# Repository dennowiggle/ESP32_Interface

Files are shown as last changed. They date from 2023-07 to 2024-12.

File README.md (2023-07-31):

# ESP32_Interface
Facilitate learning the Z80 Retro! hardware and software.

## Feature list:
ESP32-s3 based board to provide WiFi enabled features.
* RS232 connection to main Z80-Retro console via cable for telnet console access
* RS232 connection to Z80-Retro Aux com port via cable for future WiFi enabled serial download.
* Z80 bus programmer using MCP23S17 SPI IO expander devices.
  - facilitates faster Z80 bus access at 10Mhz SPI rate. 
    - Serial access still relatively slow but 25x I2C.
  - Program Flash without the need for a Raspberry Pi.
  - Might be possible to program areas of SRAM memory e.g. future WiFi file download.
* Off-board SPI using header connection to future board(s) such as FPGA video card.
  - programming FPGA plus additional SPI-FPGA debug features if needed.
* One byte, 8 bit, message register implemented in logic for handshaking with Z80.
  - uses IORQ addreess line 0xA4.
* USB OTG is present in hardware.
* SD card slot for future possiblities.

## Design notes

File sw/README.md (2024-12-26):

# ESP32 Z80 Retro! Programmer Software
Facilitate learning the Z80 Retro! hardware and software.

## Information:
The ESP32-S3 SW is in a platformio project format. If using VS Code there is a platformio plugin. Upon opening the project folder the project should self configure.

## ESP32-S3-DevkitC
* There are two versions of this dev kit supported - V1 and V1.1. If using a v1.1 module make the following change in `defines.h` for the LED to operate as expected as the two modules use different GPIO pins.

  ```#define ESP32_S3_DEVKITC_VERSION (1.1)```

## ESP32 Module Programming
* To program the board use the USB JTAG port on the module.
  - First upload the filesystem.
  - Then upload the code.
  
## WiFi Setup
* On first boot the module enters WiFi host AP mode.
  - Connect local computer to WiFi network "Z80-programmer" with password "Z80-Retro!"
  - Assign local computer IP address 192.168.4.10
  - Z80-Retro! WiFi setup IP address is 192.168.4.1
  - Open a webpage at address http://192.168.4.1 to set the WiFi parameters for WiFi client mode in the local network environment.
  - Power cycle.
  
![ESP32 Z80 Retro Programmer! WiFi Setup](docs/WiFi_Setup.jpg "WiFi Setup")

## Web Page Use
* On the local WiFi router find the new IP address that the DHCP server assigned.
* Connect local computer to local WiFi network
* Open webage and enter the IP address assigned by DHCP server to the Z80-Programmer! 

![ESP32 Z80 Retro Programmer! WiFi Setup](docs/Z80-Programmer_WebPage.jpg "Web Page Use")

## Remote Wireless Console - to ESP32 Z80 Programmer!
* There is Telnet console access to the ESP32 Z80-Programmer at the same IP address on port 2323

![Remote Wireless Console - to ESP32 Z80 Programmer!](docs/Telnet_ESP32_Port_2323.jpg "Remote Programmer Console")

## Remote Wireless Console - to Z80 Retro! Console Port
* There is Telnet console access to the Z80 Retro at the same IP address on port 23
* Connect the Z80 Retro Console port to the first ESP32 9 pin DIN. It uses the same cable as used originally in the Z80 Retro project.
* Using console access to the ESP32 Z80 Programmer configure the baud rate to match thhat of the Z80 Programmer.

![Remote Wireless Console - to Z80 Retro! Console Port](docs/Telnet_Z80Retro_Port_23.jpg "Remote Z80 Retro! Console")

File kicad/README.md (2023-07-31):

# ESP32_Interface
Facilitate learning the Z80 Retro! hardware and software.

## Description
This project adds a WiFi interface to the Z80 Retro! It has been used to facilitate telnet to the Z80 serial port, and programming the Z80 Retro! Flash memory via serial or telnet xmodem or a web interface.

## Top View
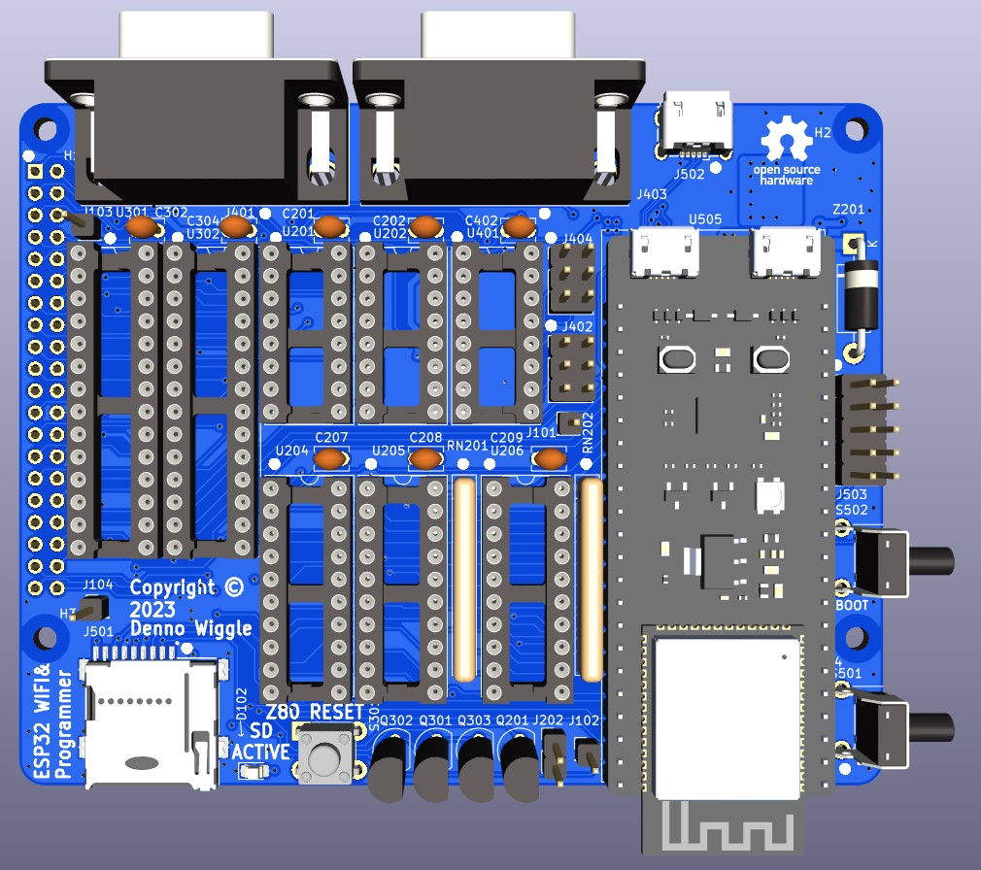
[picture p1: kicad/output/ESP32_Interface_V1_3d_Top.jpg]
ESP32 Interface Top View Board Image Top View of the ESP32 Interface Board


## Bottom View
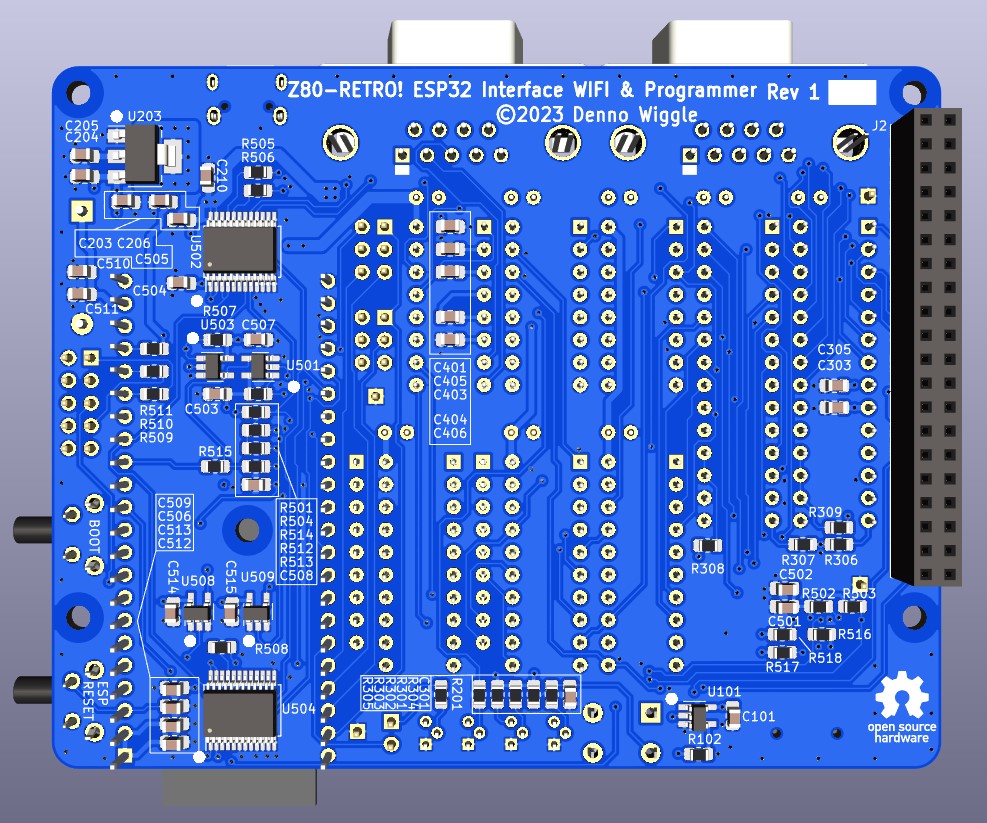
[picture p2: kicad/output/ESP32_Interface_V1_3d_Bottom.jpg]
ESP32 Interface Bottom View Board Image Bottom View of the ESP32 Interface Board


## ESP32 Interface Board Rev 1.0 Release Notes

1. The 'output' directory contains the BOM, netlist, and PDF schematic.

2. Board design used KiCad 7.0.2.

3. Silkscreen box on back side should extend around R501.

4. Holes for U505, the ESP32 module, are tight but it is possible to fit the module in. Larger pin holes would be preferred.

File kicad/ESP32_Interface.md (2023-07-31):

# ESP32_Interface.kicad_sch

## 7/9/2023 3:29:03 PM

## Eeschema 7.0.2

## Component Count:112

Ref | Qty | Value | Digikey | Datasheet | Description
----|-----|-------|---------|-----------|------------
C101, C204, C205, C403, C404, C405, C406, C501, C503, C504, C505, C506, C507, C509, C510, C512, C514, C515 | 18 | 100nF | 732-8045-1-ND | https://www.we-online.com/katalog/datasheet/885012207045.pdf | Unpolarized capacitor, small symbol
C201, C202, C207, C208, C209, C302, C304, C402 | 8 | 100n | 399-9859-1-ND‎ | https://api.kemet.com/component-edge/download/specsheet/C315C104M5U5TA7303.pdf | Unpolarized capacitor, small symbol
C203, C206, C210, C301, C303, C305, C401, C502, C511, C513 | 10 | 10uF | 1276-6455-1-ND | https://media.digikey.com/pdf/Data%20Sheets/Samsung%20PDFs/CL21A106KOQNNNG_Spec.pdf | Unpolarized capacitor, small symbol
C508 | 1 | DNL | 732-8045-1-ND | https://www.we-online.com/katalog/datasheet/885012207045.pdf | Unpolarized capacitor, small symbol
D102 | 1 | LTST-C170KGKT | 160-1414-1-ND | https://optoelectronics.liteon.com/upload/download/DS22-2000-073/LTST-C170KGKT.pdf | LED RED CLEAR SMD
H1, H2, H3, H4, H5 | 5 | MountingHole |  | ~ | Mounting Hole without connection
J2 | 1 | Conn_02x20_Counter_Clockwise |  | https://www.amazon.com/gp/product/B084Q4W1PW/ref=ppx_yo_dt_b_search_asin_title?ie=UTF8&psc=1 | Generic connector, double row, 02x20, counter clockwise pin numbering scheme (similar to DIP package numbering), script generated (kicad-library-utils/schlib/autogen/connector/)
J101, J102, J103, J104 | 4 | Conn_01x01 |  | ~ | Generic connector, single row, 01x01, script generated (kicad-library-utils/schlib/autogen/connector/)
J202 | 1 | Conn_01x02 | 2057-PH1-02-UA-ND | https://app.adam-tech.com/products/download/data_sheet/201605/ph1-xx-ua-data-sheet.pdf | Generic connector, single row, 01x02, script generated (kicad-library-utils/schlib/autogen/connector/)
J401, J403 | 2 | DB9_Male_MountingHoles | AE10970-ND | http://www.assmann-wsw.com/uploads/datasheets/ASS_4888_CO.pdf | 
J402, J404 | 2 | Conn_02x03 | 2057-PH2-06-UA-ND | https://app.adam-tech.com/products/download/data_sheet/202065/ph2-xx-ua-data-sheet.pdf | Generic connector, double row, 02x03, odd/even pin numbering scheme (row 1 odd numbers, row 2 even numbers), script generated (kicad-library-utils/schlib/autogen/connector/)
J501 | 1 | GCT_MEM2075-00-140-01-A_DP | 2073-MEM2075-00-140-01-ACT-ND | https://gct.co/files/specs/mem2075-spec.pdf | 
J502 | 1 | USB_B_Micro | 732-5960-1-ND | https://www.we-online.com/components/products/datasheet/629105150521.pdf | USB Micro Type B connector
J503 | 1 | Conn_02x05_Right_Angle | 2057-PH2RA-10-UA-ND | https://app.adam-tech.com/products/download/data_sheet/200508/ph2ra-xx-ua-data-sheet.pdf | Generic connector, double row, 02x05, odd/even pin numbering scheme (row 1 odd numbers, row 2 even numbers), script generated (kicad-library-utils/schlib/autogen/connector/)
Q201, Q301, Q302, Q303 | 4 | PN2222 | 1514-PN2222APBFREE-ND | https://my.centralsemi.com/datasheets/PN2221-2222A.PDF | NPN transistor, emitter/base/collector
R102, R201, R305 | 3 | 1K | 311-1.0KARCT-ND | https://www.yageo.com/upload/media/product/productsearch/datasheet/rchip/PYu-RC_Group_51_RoHS_L_12.pdf | Resistor, US symbol
R301, R302, R303, R308, R309, R501, R502, R503, R504, R507, R511, R516, R517, R518 | 14 | 10K | 311-10KARCT-ND | https://www.yageo.com/upload/media/product/productsearch/datasheet/rchip/PYu-RC_Group_51_RoHS_L_12.pdf | Resistor, US symbol
R304 | 1 | 47K | 311-47KARCT-ND | https://www.yageo.com/upload/media/product/productsearch/datasheet/rchip/PYu-RC_Group_51_RoHS_L_12.pdf | Resistor, US symbol
R306, R307, R505, R506, R508, R509, R510 | 7 | 33R | 311-33ARCT-ND | https://www.yageo.com/upload/media/product/productsearch/datasheet/rchip/PYu-RC_Group_51_RoHS_L_12.pdf | Resistor, US symbol
R512, R513 | 2 | 0R | 311-0.0ARCT-ND | https://www.yageo.com/upload/media/product/productsearch/datasheet/rchip/PYu-RC_Group_51_RoHS_L_12.pdf | Resistor, US symbol
R514, R515 | 2 | DNL | 311-0.0ARCT-ND | https://www.yageo.com/upload/media/product/productsearch/datasheet/rchip/PYu-RC_Group_51_RoHS_L_12.pdf | Resistor, US symbol
RN201, RN202 | 2 | 10K | 4609X-101-103LF-ND | https://www.bourns.com/docs/Product-Datasheets/4600x.pdf | 8 resistor network, star topology, bussed resistors, small symbol
S301 | 1 | 1825910-6 | 450-1650-ND | https://www.te.com/commerce/DocumentDelivery/DDEController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 | SWITCH TACTILE SPST-NO 0.05A 24V
S501 | 1 | 1-1825027-2 | 1-1825027-2-ND | https://www.te.com/commerce/DocumentDelivery/DDEController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 | SWITCH TACTILE SPST-NO 0.05A 24V
S502 | 1 | 1825027-8 | 450-1657-ND | https://www.te.com/commerce/DocumentDelivery/DDEController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 | SWITCH TACTILE SPST-NO 0.05A 24V
U101 | 1 | SN74LVC1G04DBVR | 296-11599-1-ND | http://www.ti.com/general/docs/suppproductinfo.tsp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 | IC INVERTER 1CH 1-INP SOT23-5
U201, U202 | 2 | 74LS138 | 296-1728-5-ND | http://www.ti.com/lit/gpn/sn74LS138 | Decoder 3 to 8 active low outputs
U203 | 1 | NCP1117LPST33T3G | NCP1117LPST33T3GOSCT-ND | https://www.onsemi.com/pdf/datasheet/ncp1117lp-d.pdf | IC REG LINEAR 3.3V 1A SOT223
U204 | 1 | 74HC374 | 296-12806-5-ND | https://www.ti.com/lit/ds/symlink/cd74hct374.pdf | 8-bit Register, 3-state outputs
U205 | 1 | 74LS244 | 296-1653-5-ND | https://www.ti.com/lit/ds/symlink/sn74ls241.pdf | Octal Buffer and Line Driver With 3-State Output, active-low enables, non-inverting outputs
U206 | 1 | 74LVC245A | 296-8503-5-ND | http://www.ti.com/lit/ds/symlink/sn74lvc245a.pdf | Octal BUS Transceivers, 3-State outputs
U301, U302 | 2 | MCP23S17_SP | MCP23S17-E/SP-ND | http://ww1.microchip.com/downloads/en/DeviceDoc/20001952C.pdf | 16-bit I/O expander, SPI, interrupts, w pull-ups, SPDIP-28
U401 | 1 | ICL3232CPZ | ICL3232CPZ-ND‎ | https://www.renesas.com/us/en/document/dst/icl3221-icl3222-icl3223-icl3232-icl3241-icl3243-datasheet | 3.0V to 5.5V, Low-Power, up to 1Mbps, True RS-232 Transceivers Using Four 0.1μF External Capacitors
U501, U503, U508, U509 | 4 | SN74LVC1G125DBVR | 296-11603-1-ND | http://www.ti.com/general/docs/suppproductinfo.tsp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 | IC BUF NON-INVERT 5.5V SOT23-5
U502, U504 | 2 | SN74LVC8T245DBR | 296-21065-1-ND | https://www.ti.com/lit/ds/symlink/sn74lvc8t245.pdf | Octal BUS Transceivers, 3-State outputs
U505 | 1 | ESP32-S3-DevKitC | 1965-ESP32-S3-DEVKITC-1-N8R2-ND | https://docs.espressif.com/projects/esp-idf/en/latest/esp32s3/hw-reference/esp32s3/user-guide-devkitc-1.html | ESP32-S3-DevKitC
Z201 | 1 | SA5.0A | SA5.0ALFCT-ND | https://www.littelfuse.com/~/media/electronics/datasheets/tvs_diodes/littelfuse_tvs_diode_sa_datasheet.pdf.pdf | TVS DIODE 5VWM 9.2VC DO214AA

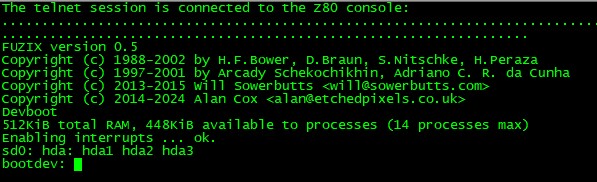
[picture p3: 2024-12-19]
sw/docs/Telnet_Z80Retro_Port_23.jpg

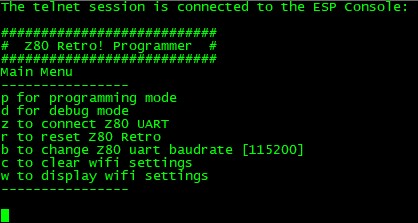
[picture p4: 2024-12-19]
sw/docs/Telnet_ESP32_Port_2323.jpg

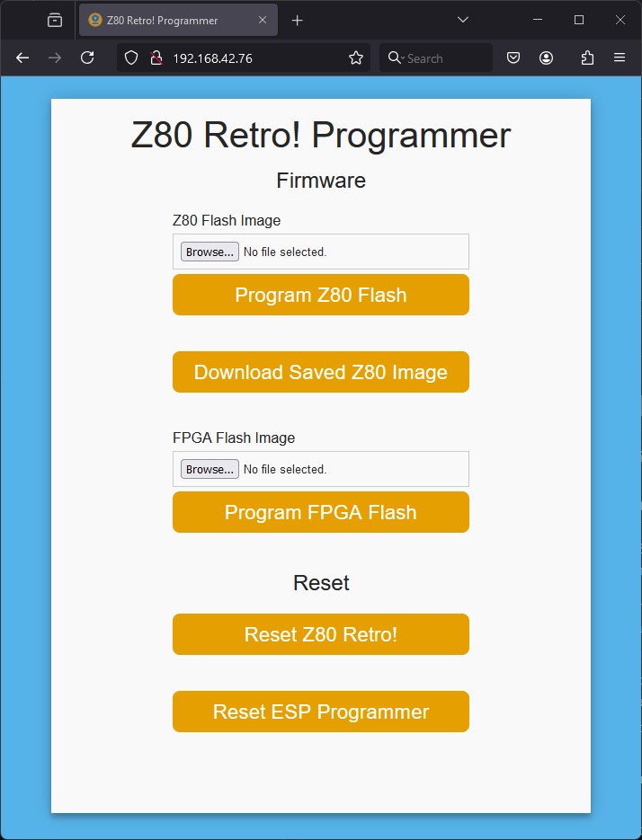
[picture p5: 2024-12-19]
sw/docs/Z80-Programmer_WebPage.jpg

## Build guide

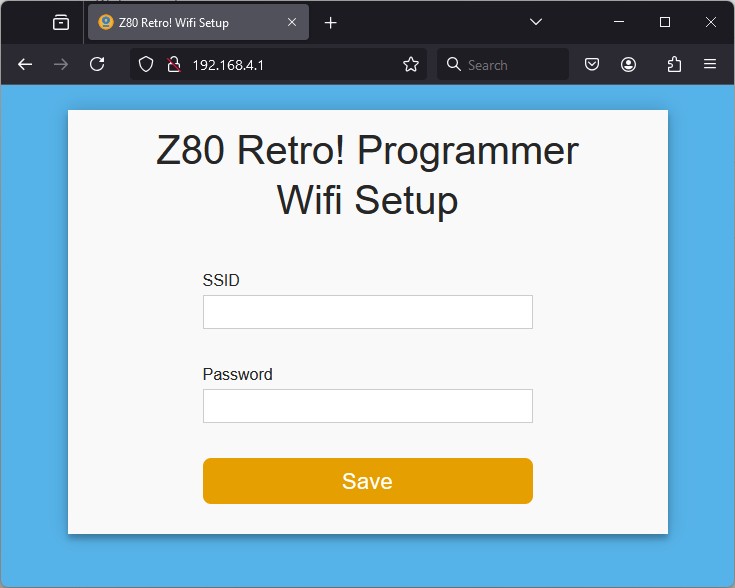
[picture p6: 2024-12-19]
sw/docs/WiFi_Setup.jpg

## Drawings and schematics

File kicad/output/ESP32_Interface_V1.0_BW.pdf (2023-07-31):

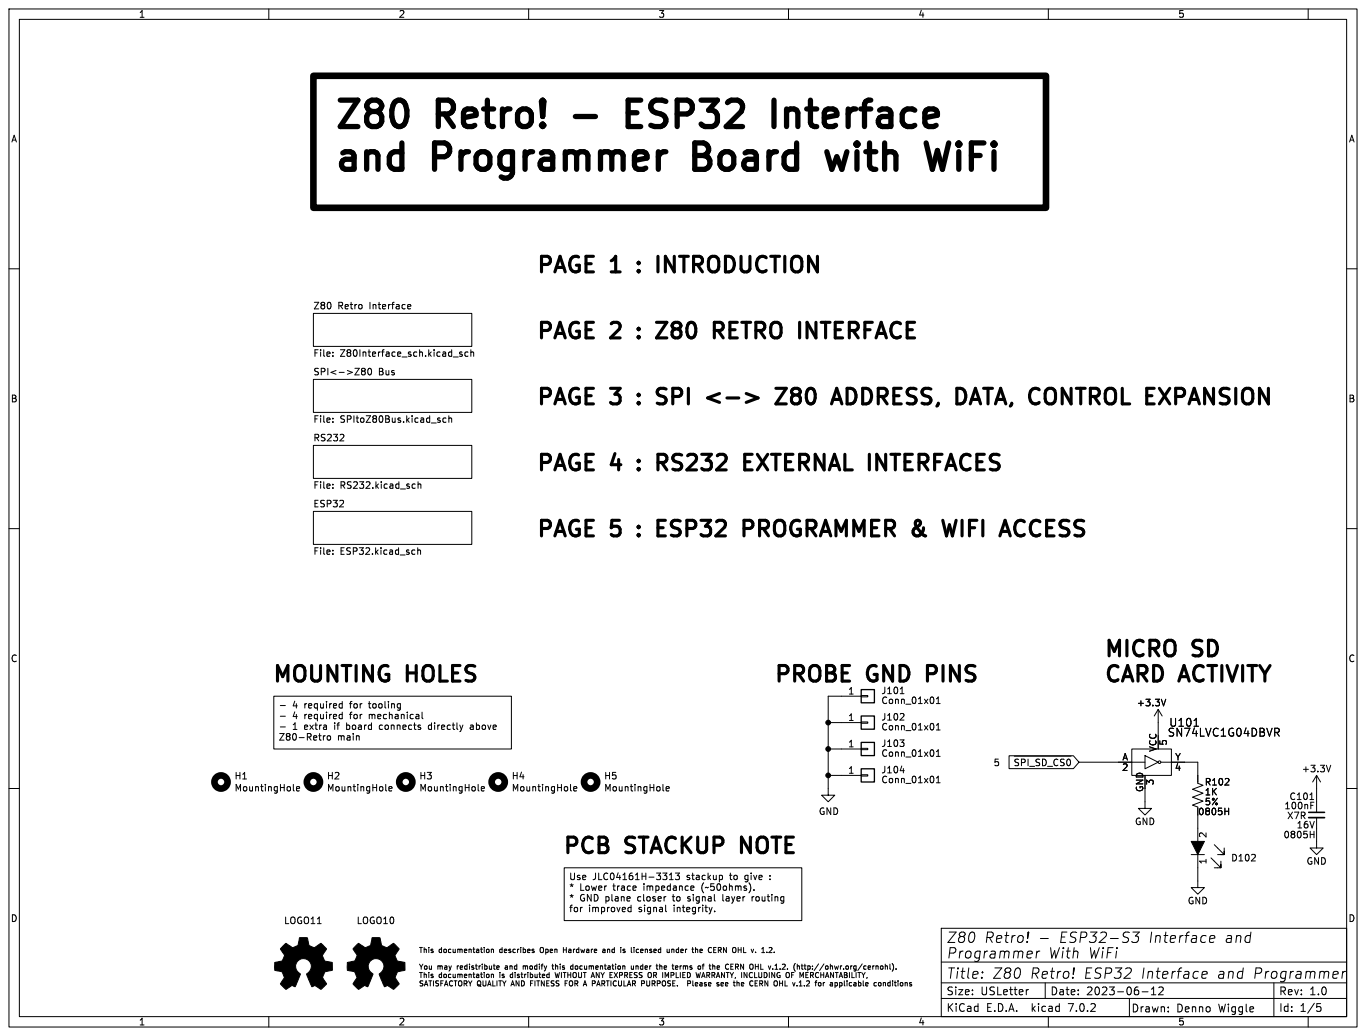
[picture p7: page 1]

Z80 Retro! - ESP32 Interface
and Programmer Board with WiFi

for improved signal integrity.

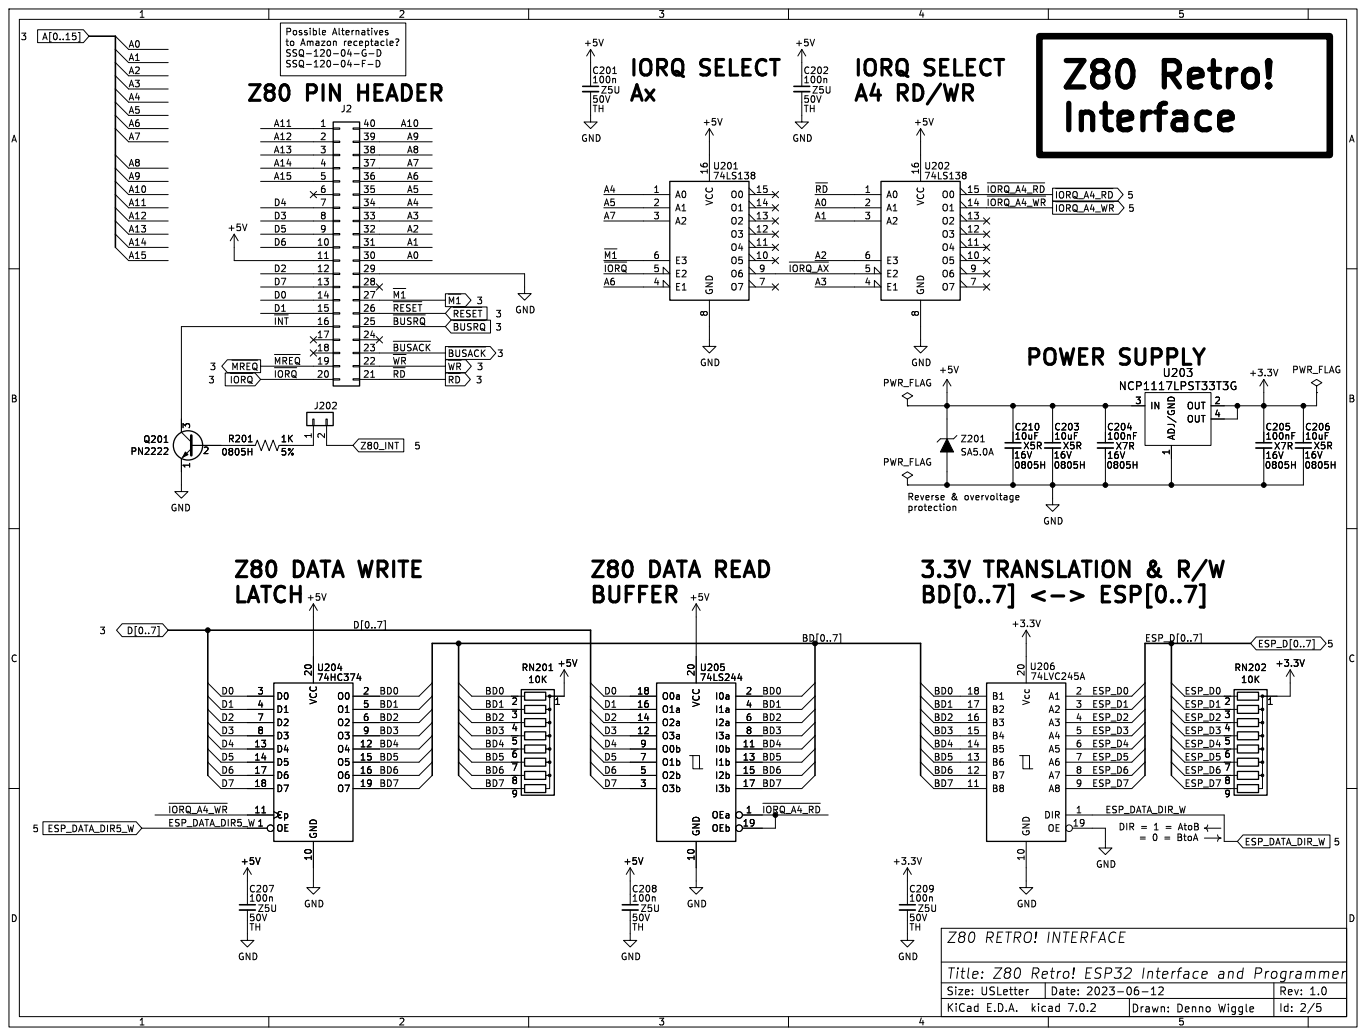
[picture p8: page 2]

Possible Alternatives
to Amazon receptacle? SSQ-120-04-G-D

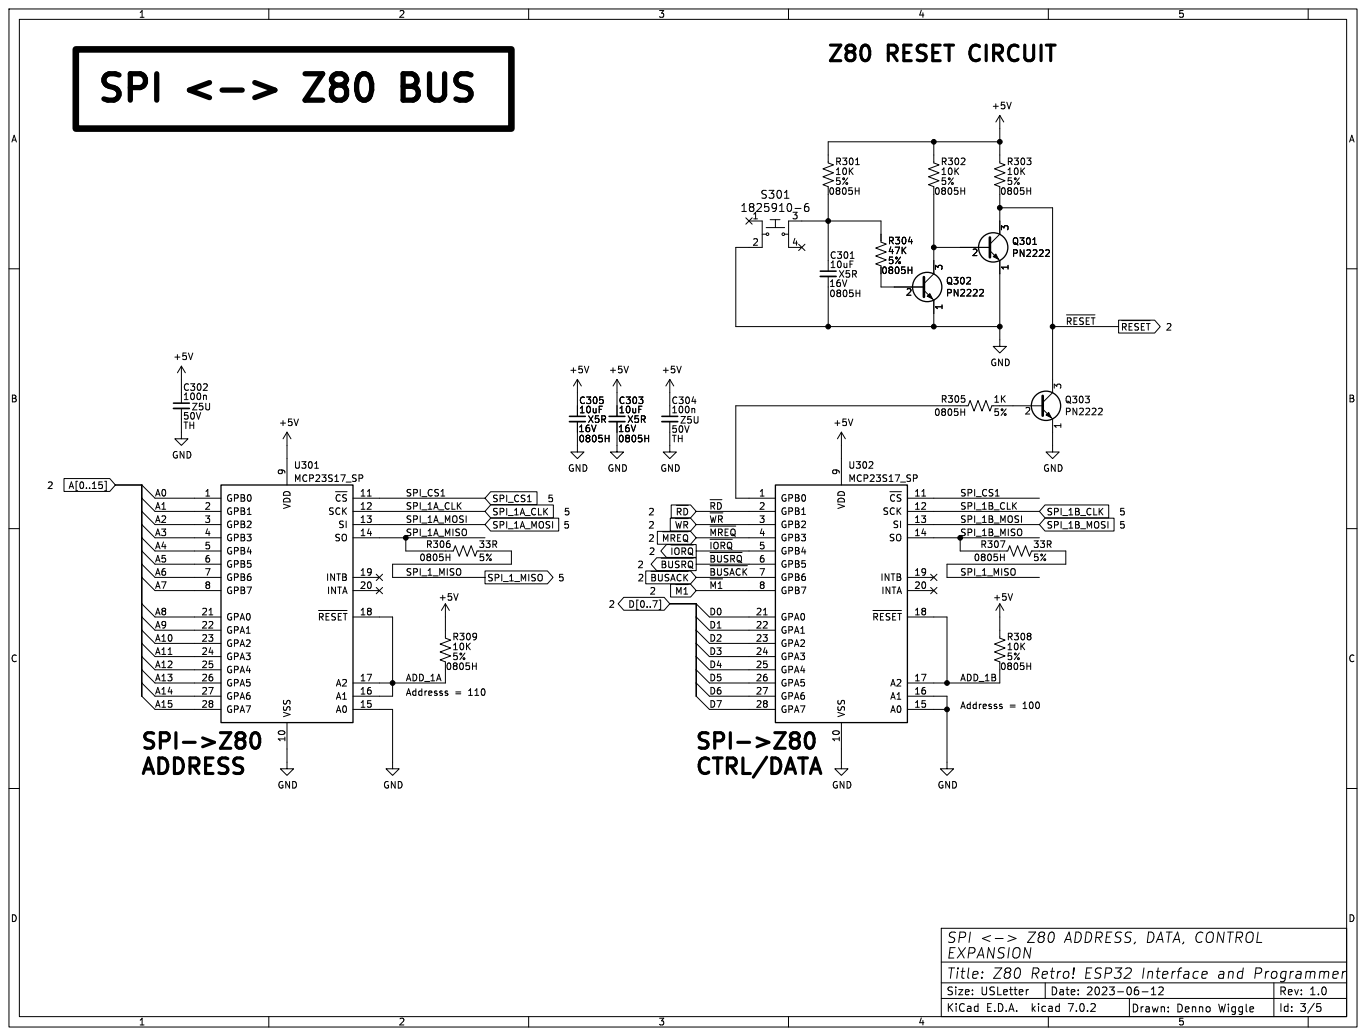
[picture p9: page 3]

3 Q303 PN2222 ~{WR} SPI_1A_MOSI 5 2 ~{MREQ} 2 ~{RD} 2 ~{BUSRQ} 2 ~{BUSACK} 2 ~{IORQ} 2

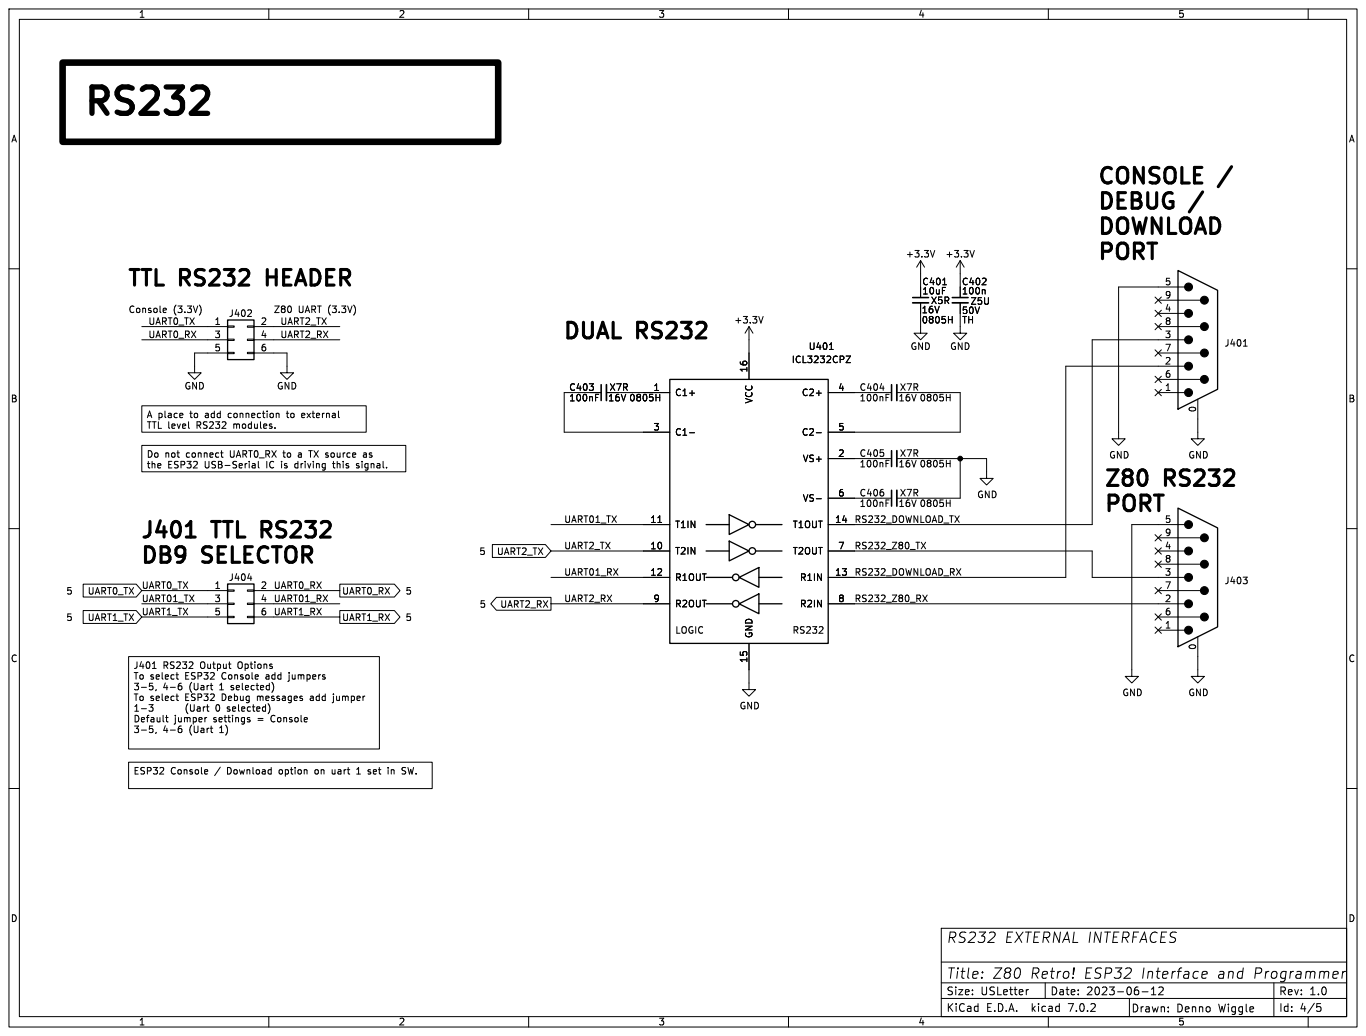
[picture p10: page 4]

Do not connect UART0_RX to a TX source as

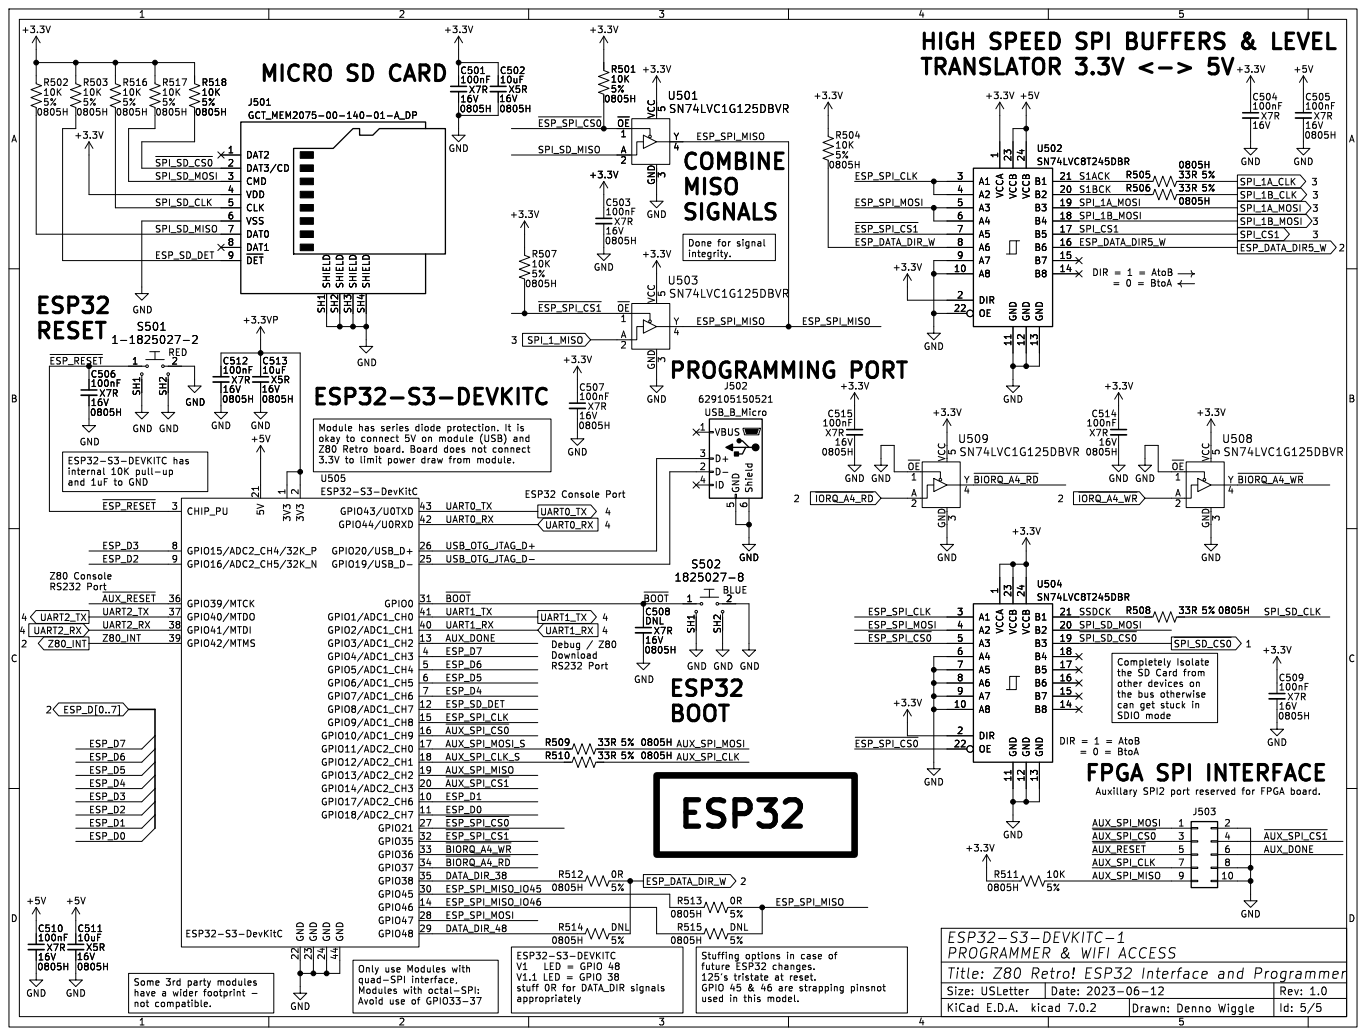
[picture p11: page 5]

1 A8 10 GND 11 GND 12 GND 13 B8 14 B7 15 B6 16 B5 17 B4 18 B3 19 DIR 2 B2 20 B1 21 OE 22 VCCB 23 VCCB 24 A1 3 A2 4 A3 5 A4 6 A5 7 A6 8 A7 9 U502 SN74LVC8T245DBR GND GND

1 A8 10 GND 11 GND 12 GND 13 B8 14 B7 15 B6 16 B5 17 B4 18 B3 19 DIR 2 B2 20 B1 21 OE 22 VCCB 23 VCCB 24 A1 3 A2 4 A3 5 A4 6 A5 7 A6 8 A7 9 R505 33R 5%

2 GPIO14/ADC2_CH3 20 5V 21 GND 22 GND 23 GND 24 GPIO19/USB_D- 25 GPIO20/USB_D+ 26 GPIO21 27 GPIO47 28 GPIO48 29 CHIP_PU 3 GPIO45 30 GPIO0 31 GPIO35 32 GPIO36 33 GPIO37 34 GPIO38 35 GPIO39/MTCK 36 GPIO40/MTDO 37 GPIO41/MTDI 38 GPIO4/ADC1_CH3 4 GPIO5/ADC1_CH4 5 GPIO6/ADC1_CH5 6 GPIO7/ADC1_CH6 7 GPIO15/ADC2_CH4/32K_P 8 GPIO16/ADC2_CH5/32K_N 9 U505 ESP32-S3-DevKitC

1 A8 10 GND 11 GND 12 GND 13 B8 14 B7 15 B6 16 B5 17 B4 18 B3 19 DIR 2 B2 20 B1 21 OE 22 VCCB 23 VCCB 24 A1 3 A2 4 A3 5 A4 6 A5 7 A6 8 A7 9 U504 SN74LVC8T245DBR

1 A8 10 GND 11 GND 12 GND 13 B8 14 B7 15 B6 16 B5 17 B4 18 B3 19 DIR 2 B2 20 B1 21 OE 22 VCCB 23 VCCB 24 A1 3 A2 4 A3 5 A4 6 A5 7 A6 8 A7 9 R508 33R 5% 0805H

the SD Card from
other devices on
the bus otherwise

Only use Modules with

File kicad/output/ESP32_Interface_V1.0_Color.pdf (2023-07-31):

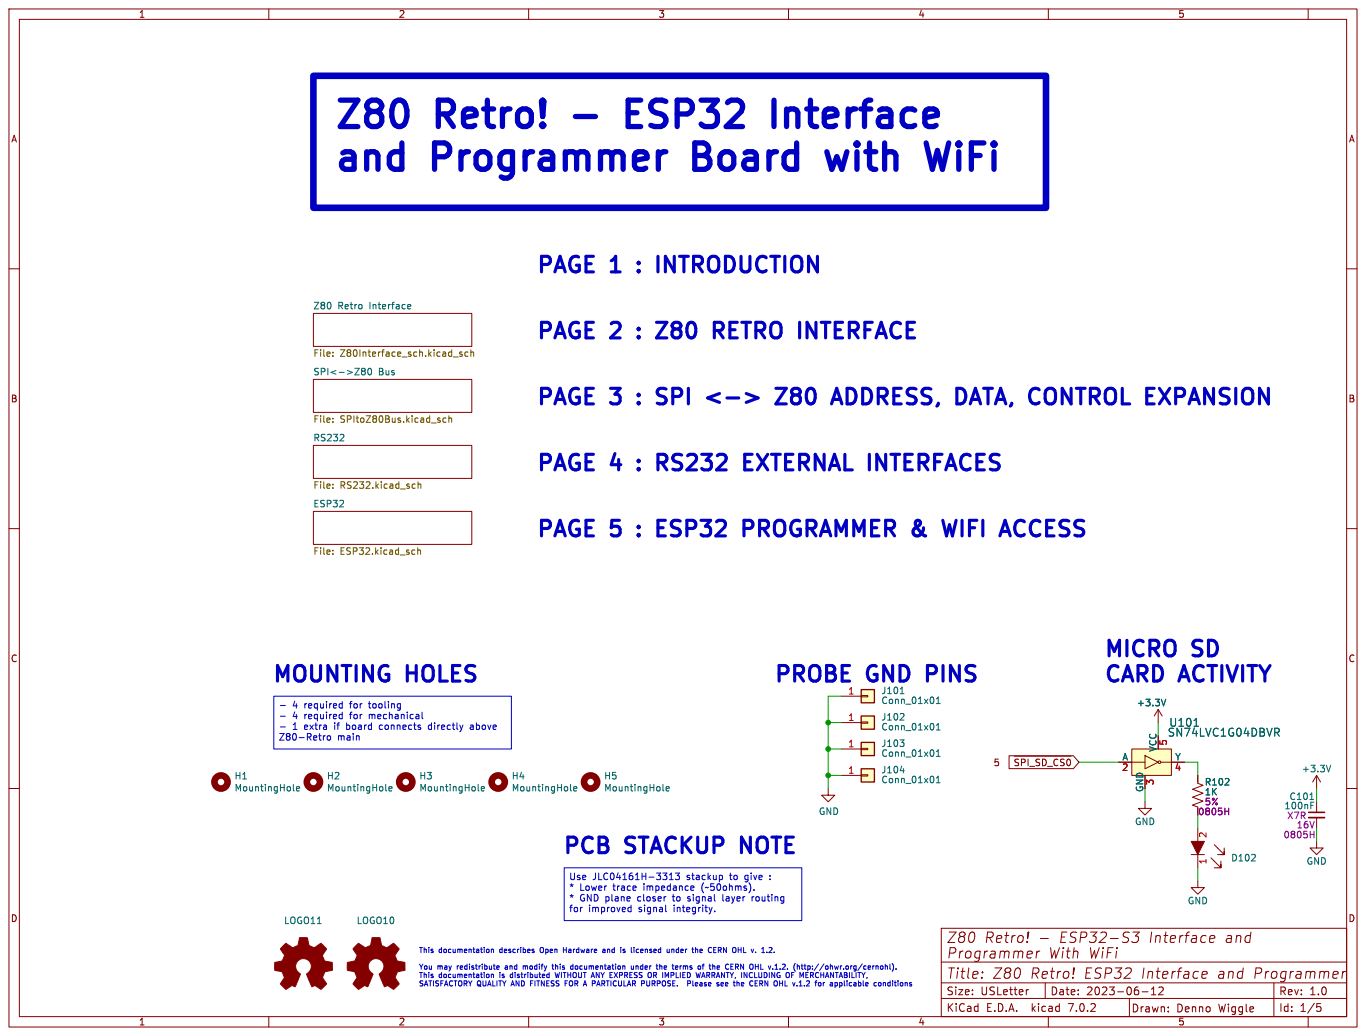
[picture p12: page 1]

Z80 Retro! - ESP32 Interface
and Programmer Board with WiFi

for improved signal integrity.

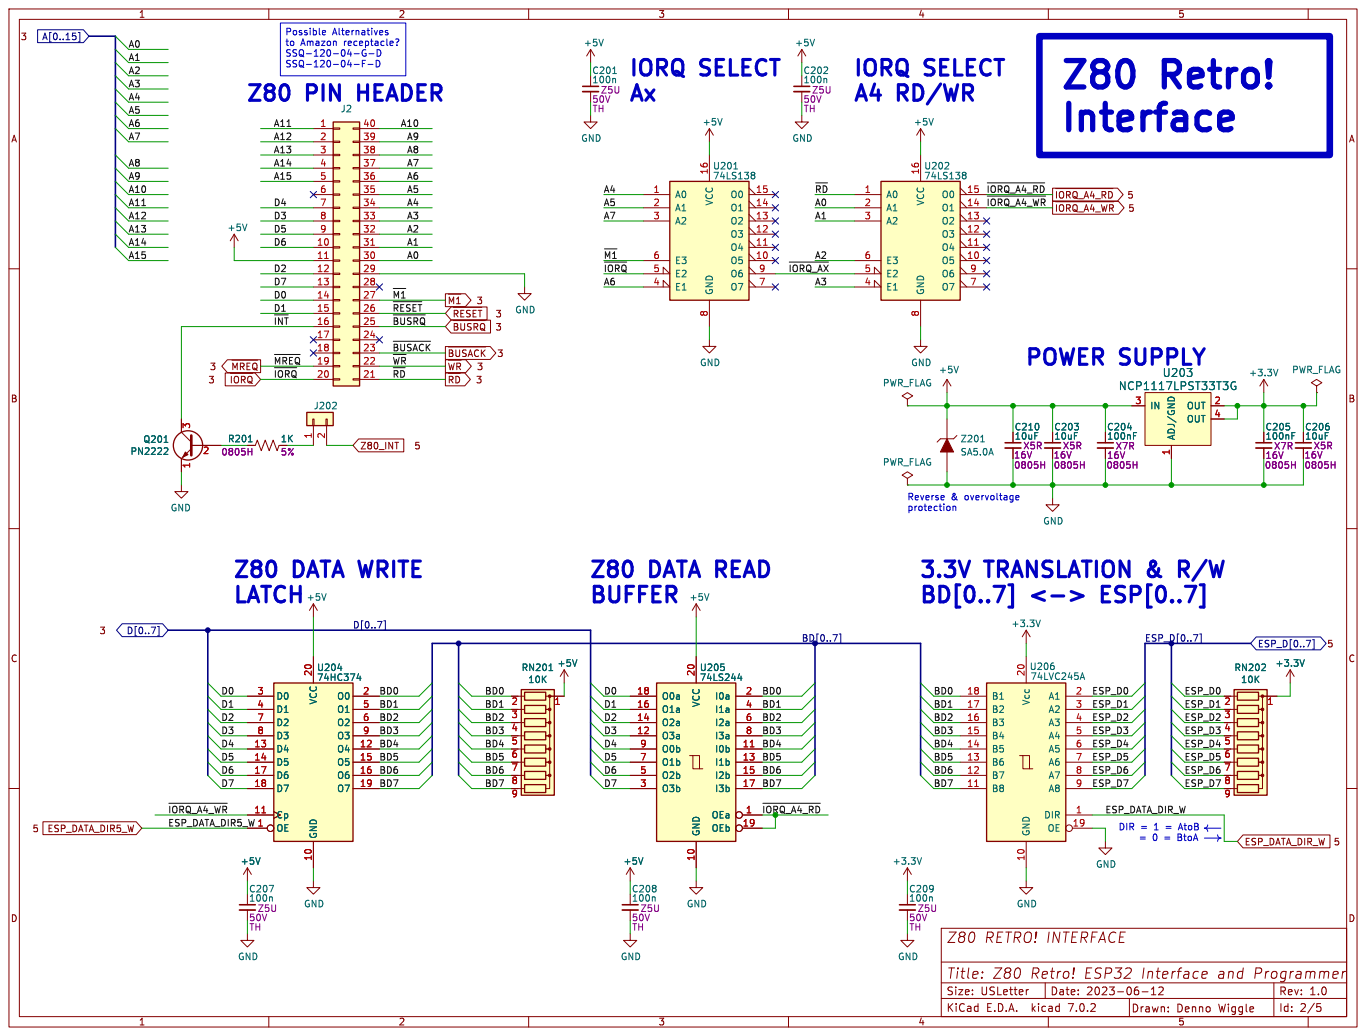
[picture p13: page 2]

Possible Alternatives
to Amazon receptacle? SSQ-120-04-G-D

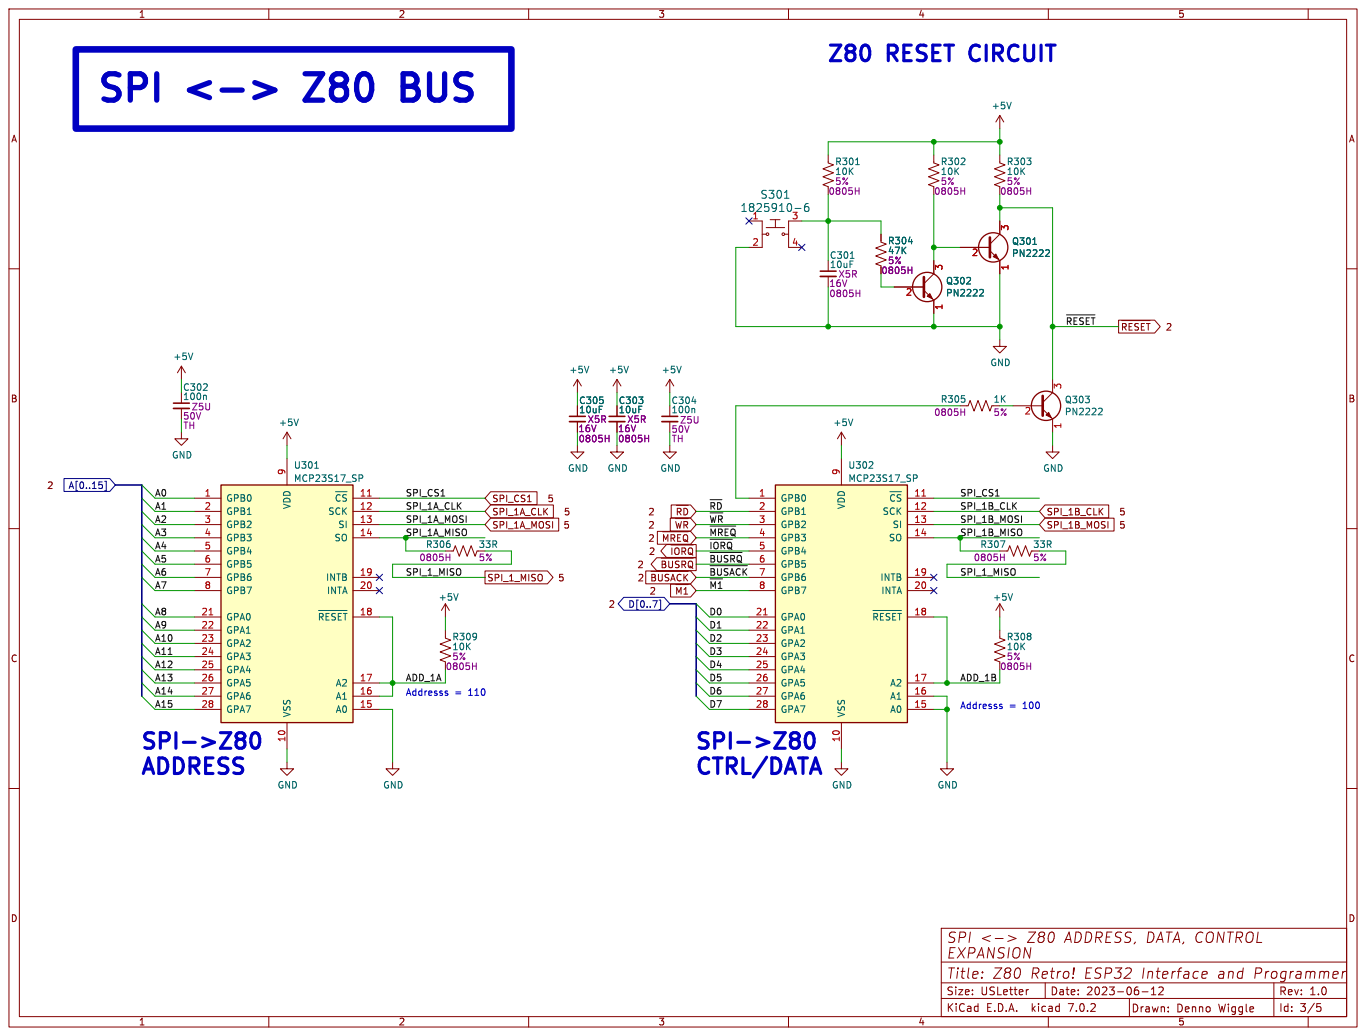
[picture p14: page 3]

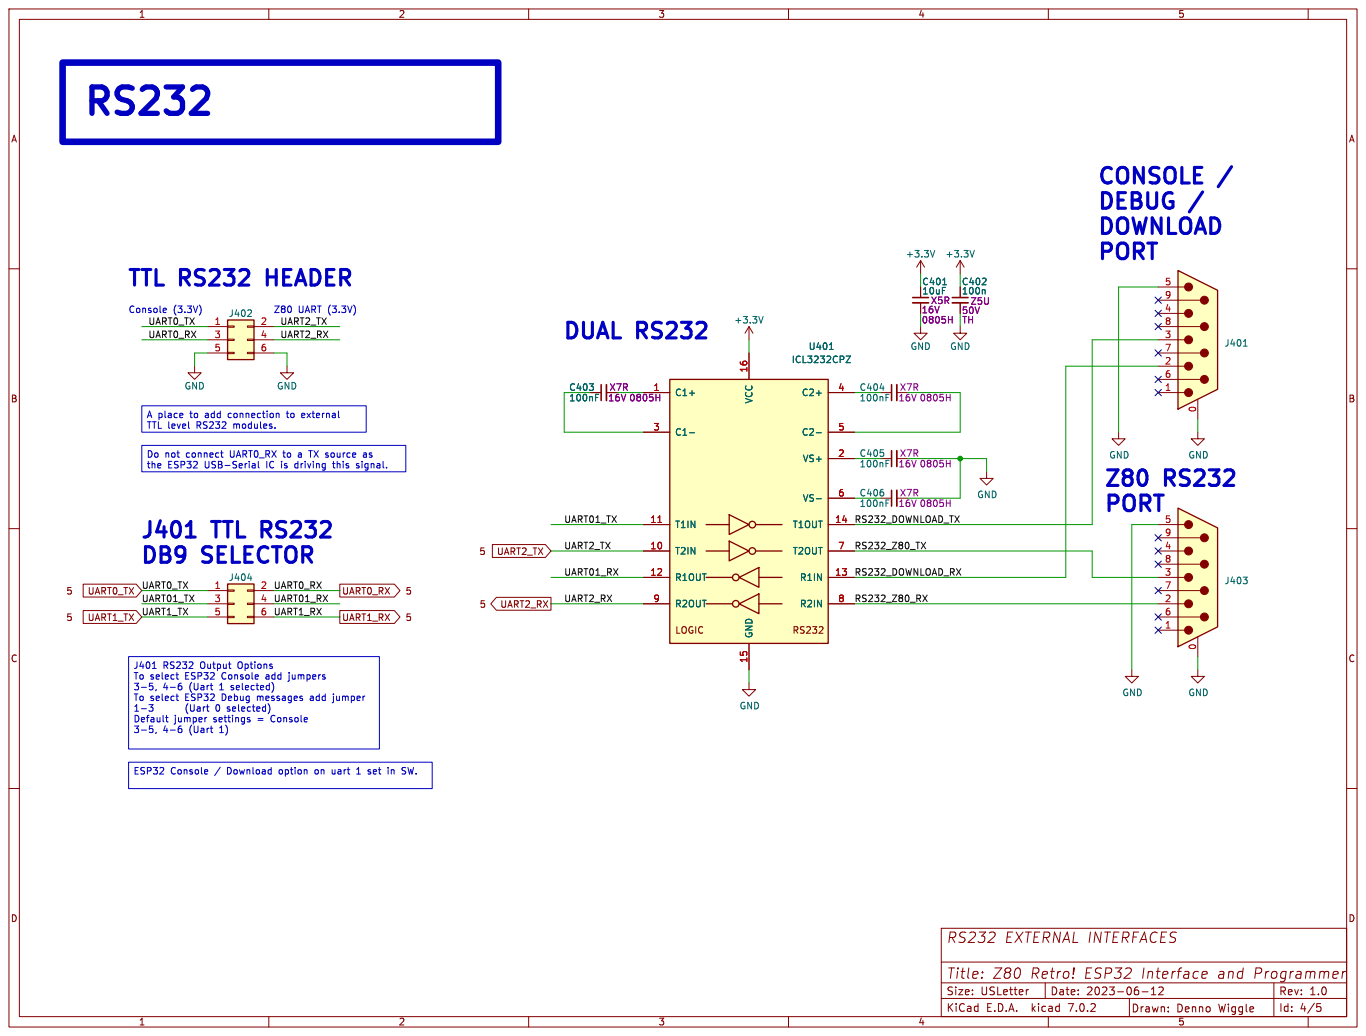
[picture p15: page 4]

Do not connect UART0_RX to a TX source as

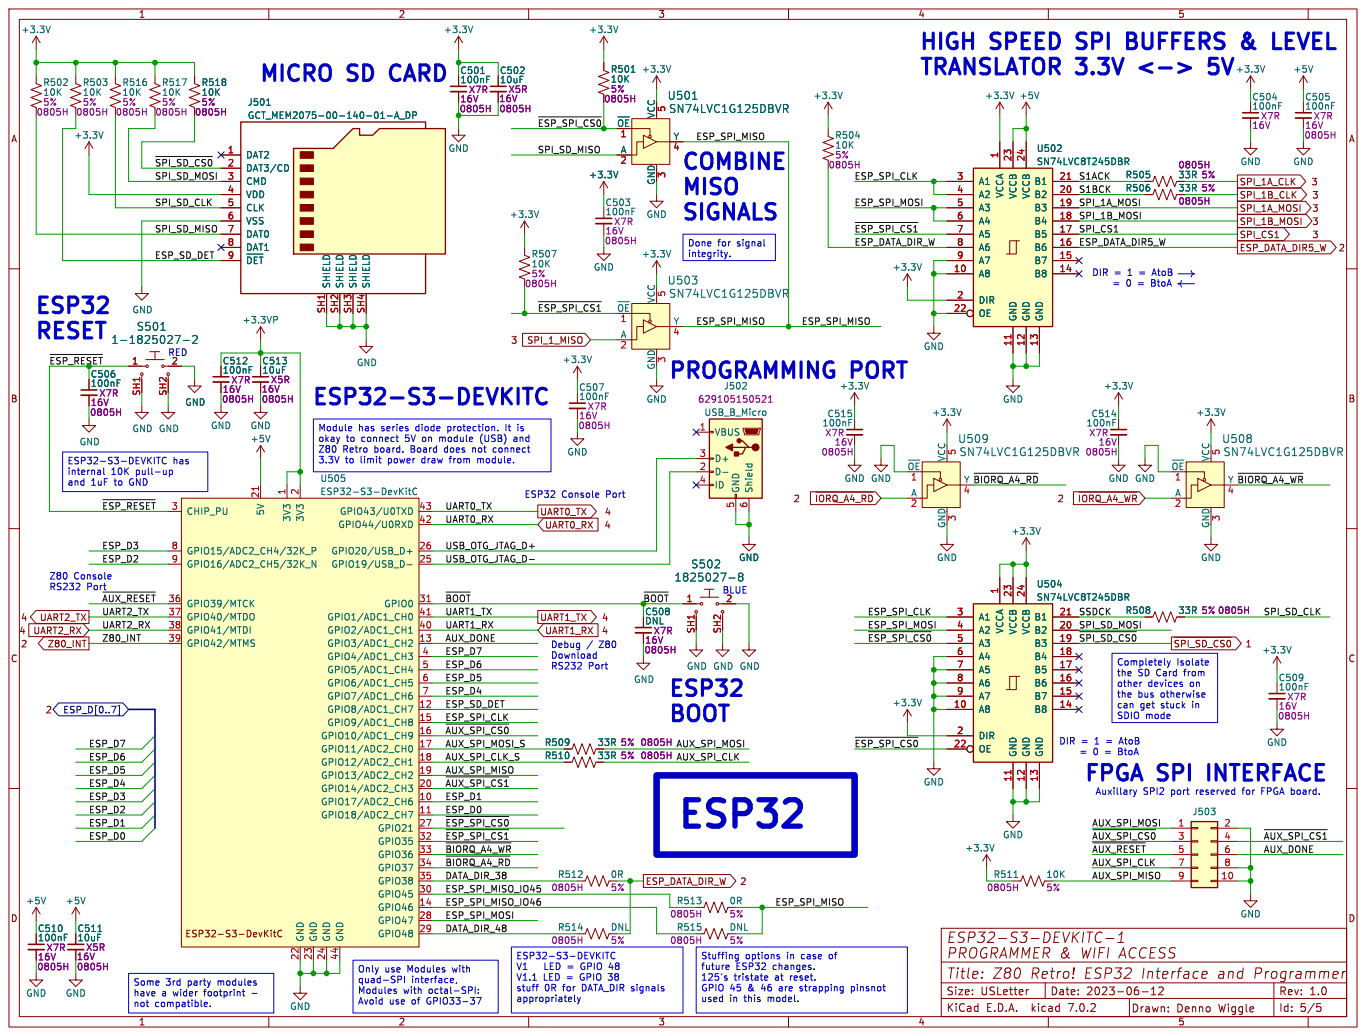
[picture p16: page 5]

HIGH SPEED SPI BUFFERS & LEVEL

BLUE MICRO SD CARD

1 A8 10 GND 11 GND 12 GND 13 B8 14 B7 15 B6 16 B5 17 B4 18 B3 19 DIR 2 B2 20 B1 21 OE 22 VCCB 23 VCCB 24 A1 3 A2 4 A3 5 A4 6 A5 7 A6 8 A7 9 U502 SN74LVC8T245DBR GND

1 A8 10 GND 11 GND 12 GND 13 B8 14 B7 15 B6 16 B5 17 B4 18 B3 19 DIR 2 B2 20 B1 21 OE 22 VCCB 23 VCCB 24 A1 3 A2 4 A3 5 A4 6 A5 7 A6 8 A7 9 R505 33R 5%

2 GPIO14/ADC2_CH3 20 5V 21 GND 22 GND 23 GND 24 GPIO19/USB_D- 25 GPIO20/USB_D+ 26 GPIO21 27 GPIO47 28 GPIO48 29 CHIP_PU 3 GPIO45 30 GPIO0 31 GPIO35 32 GPIO36 33 GPIO37 34 GPIO38 35 GPIO39/MTCK 36 GPIO40/MTDO 37 GPIO41/MTDI 38 GPIO4/ADC1_CH3 4 GPIO5/ADC1_CH4 5 GPIO6/ADC1_CH5 6 GPIO7/ADC1_CH6 7 GPIO15/ADC2_CH4/32K_P 8 GPIO16/ADC2_CH5/32K_N 9 U505 ESP32-S3-DevKitC

1 A8 10 GND 11 GND 12 GND 13 B8 14 B7 15 B6 16 B5 17 B4 18 B3 19 DIR 2 B2 20 B1 21 OE 22 VCCB 23 VCCB 24 A1 3 A2 4 A3 5 A4 6 A5 7 A6 8 A7 9 U504 SN74LVC8T245DBR

1 A8 10 GND 11 GND 12 GND 13 B8 14 B7 15 B6 16 B5 17 B4 18 B3 19 DIR 2 B2 20 B1 21 OE 22 VCCB 23 VCCB 24 A1 3 A2 4 A3 5 A4 6 A5 7 A6 8 A7 9 R508 33R 5% 0805H

the SD Card from
other devices on
the bus otherwise

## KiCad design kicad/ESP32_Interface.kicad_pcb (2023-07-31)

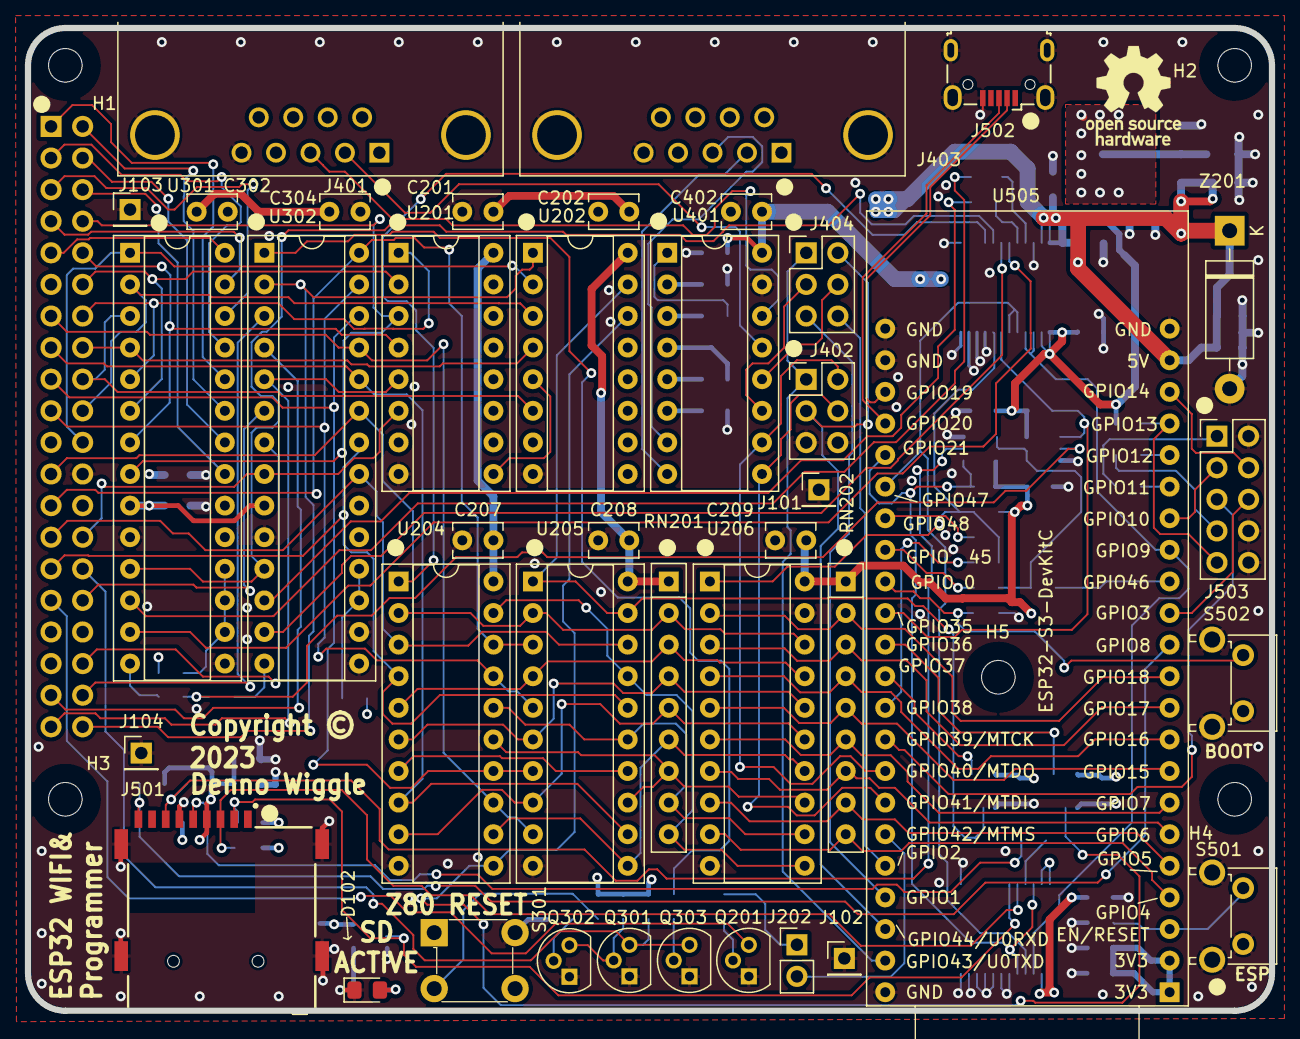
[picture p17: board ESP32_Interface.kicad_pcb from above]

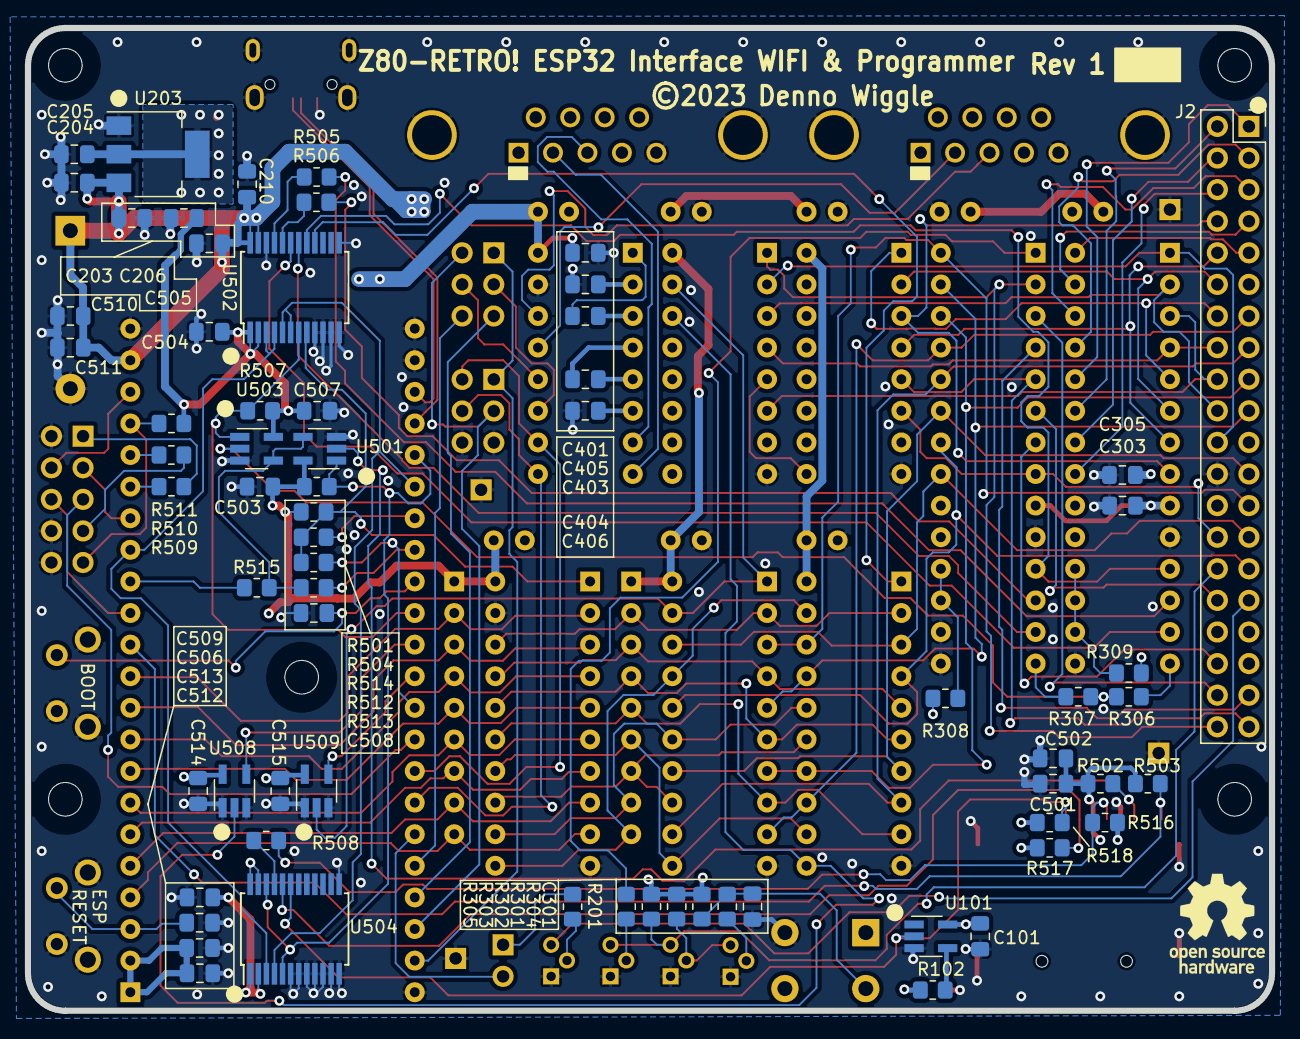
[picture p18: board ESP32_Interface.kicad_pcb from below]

Board: 4 copper layers, 100.0 x 79.0 mm, 114 parts (68 on the bottom side), 128 nets.

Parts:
C101, C204, C205, C403, C404, C405, C406, C501, C503, C504, C505, C506, C507, C509, C510, C512, C514, C515: 100nF; C_0805_2012Metric_Pad1.18x1.45mm_HandSolder
C201, C202, C207, C208, C209, C302, C304, C402: 100n; C_Disc_D3.8mm_W2.6mm_P2.50mm
C203, C206, C210, C301, C303, C305, C401, C502, C511, C513: 10uF; C_0805_2012Metric_Pad1.18x1.45mm_HandSolder
C508: DNL; C_0805_2012Metric_Pad1.18x1.45mm_HandSolder
D102: LTST-C170KGKT; LED_0805_2012Metric_Pad1.15x1.40mm_HandSolder
H1, H2, H3, H4, H5: MountingHole; MountingHole_2.7mm_M2.5_DIN965
J2: Conn_02x20_Counter_Clockwise; PinSocket_2x20_P2.54mm_Vertical_clockwise
J101, J102, J103, J104: Conn_01x01; PinHeader_1x01_P2.54mm_Vertical
J202: Conn_01x02; PinHeader_1x02_P2.54mm_Vertical
J401, J403: DB9_Male_MountingHoles; DSUB-9_Male_Horizontal_P2.77x2.84mm_EdgePinOffset7.70mm_Hou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
J402, J404: Conn_02x03; PinHeader_2x03_P2.54mm_Vertical
J501: GCT_MEM2075-00-140-01-A_DP; GCT_MEM2075-00-140-01-A
J502: USB_B_Micro; USB_Micro-B_Wuerth_629105150521
J503: Conn_02x05; PinHeader_2x05_P2.54mm_Vertical
LOGO10, LOGO11: Logo_Open_Hardware_Small; OSHW-Logo_7.5x8mm_SilkScreen
Q201, Q301, Q302, Q303: PN2222; TO-92L
R102, R201, R305: 1K; R_0805_2012Metric_Pad1.20x1.40mm_HandSolder
R301, R302, R303, R308, R309, R501, R502, R503, R504, R507, R511, R516, R517, R518: 10K; R_0805_2012Metric_Pad1.20x1.40mm_HandSolder
R304: 47K; R_0805_2012Metric_Pad1.20x1.40mm_HandSolder
R306, R307, R505, R506, R508, R509, R510: 33R; R_0805_2012Metric_Pad1.20x1.40mm_HandSolder
R512, R513: 0R; R_0805_2012Metric_Pad1.20x1.40mm_HandSolder
R514, R515: DNL; R_0805_2012Metric_Pad1.20x1.40mm_HandSolder
RN201, RN202: 10K; R_Array_SIP9
S301: 1825910-6; Switch_Tactile_THT_6x6mm
S501: 1-1825027-2; SW_Tactile_SPST_Angled_PTS645Vx83-2LFS
S502: 1825027-8; SW_Tactile_SPST_Angled_PTS645Vx83-2LFS
U101: SN74LVC1G04DBVR; SOT-23-5_HandSoldering
U201, U202: 74LS138; DIP-16_W7.62mm_Socket
U203: NCP1117LPST33T3G; SOT-223
U204: 74HC374; DIP-20_W7.62mm_Socket
U205: 74LS244; DIP-20_W7.62mm_Socket
U206: 74LVC245A; DIP-20_W7.62mm_Socket
U301, U302: MCP23S17_SP; DIP-28_W7.62mm_Socket
U401: ICL3232CPZ; DIP-16_W7.62mm_Socket
U501, U503, U508, U509: SN74LVC1G125DBVR; SOT-23-5_HandSoldering
U502, U504: SN74LVC8T245DBR; SSOP-24_5.3x8.2mm_P0.65mm
U505: ESP32-S3-DevKitC
Z201: SA5.0A; D_DO-15_P12.70mm_Horizontal

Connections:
+3.3V: C101.1, C205.1, C206.1, C209.1, C401.1, C402.1, C501.1, C502.1, C503.1, C504.1, C507.1, C509.1, C514.1, C515.1, J501.4 (VDD), R501.1, R502.1, R503.1, R504.1, R507.1, R511.1, R516.1, R517.1, R518.1, RN202.1 (common), U101.5 (VCC), U203.2 (OUT), U203.4 (OUT), U206.20 (Vcc), U401.16 (VCC), U501.5 (VCC), U502.1 (VCCA), U502.2 (DIR), U503.5 (VCC), U504.1 (VCCA), U504.2 (DIR), U504.23 (VCCB), U504.24 (VCCB), U508.5 (VCC), U509.5 (VCC)
+3.3VP: C512.1, C513.1, U505.1 (3V3), U505.2 (3V3)
+5V: C201.1, C202.1, C203.1, C204.1, C207.1, C208.1, C210.1, C302.1, C303.1, C304.1, C305.1, C505.1, C510.1, C511.1, J2.11, R301.1, R302.1, R303.1, R308.1, R309.1, RN201.1 (common), U201.16 (VCC), U202.16 (VCC), U203.3 (IN), U204.20 (VCC), U205.20 (VCC), U301.9 (VDD), U302.9 (VDD), U502.23 (VCCB), U502.24 (VCCB), U505.21 (5V), Z201.1
/ESP32/AUX_DONE: J503.6, U505.13 (GPIO3/ADC1_CH2)
/ESP32/AUX_SPI_CLK: J503.7, R510.2
/ESP32/AUX_SPI_CLK_S: R510.1, U505.18 (GPIO12/ADC2_CH1)
/ESP32/AUX_SPI_MISO: J503.9, R511.2, U505.19 (GPIO13/ADC2_CH2)
/ESP32/AUX_SPI_MOSI: J503.1, R509.2
/ESP32/AUX_SPI_MOSI_S: R509.1, U505.17 (GPIO11/ADC2_CH0)
/ESP32/DATA_DIR_38: R512.1, U505.35 (GPIO38)
/ESP32/DATA_DIR_48: R514.1, U505.29 (GPIO48)
/ESP32/ESP_SD_DET: J501.9 (~DET), R503.2, U505.12 (GPIO8/ADC1_CH7)
/ESP32/ESP_SPI_CLK: U502.3 (A1), U502.4 (A2), U504.3 (A1), U505.15 (GPIO9/ADC1_CH8)
/ESP32/ESP_SPI_MISO: R513.2, R515.2, U501.4 (Y), U503.4 (Y)
/ESP32/ESP_SPI_MISO_IO45: R513.1, U505.30 (GPIO45)
/ESP32/ESP_SPI_MISO_IO46: R515.1, U505.14 (GPIO46)
/ESP32/ESP_SPI_MOSI: U502.5 (A3), U502.6 (A4), U504.4 (A2), U505.28 (GPIO47)
/ESP32/S1ACK: R505.1, U502.21 (B1)
/ESP32/S1BCK: R506.1, U502.20 (B2)
/ESP32/SPI_SD_CLK: J501.5 (CLK), R508.2, R516.2
/ESP32/SPI_SD_MISO: J501.7 (DAT0), R502.2, U501.2 (A)
/ESP32/SPI_SD_MOSI: J501.3 (CMD), R517.2, U504.20 (B2)
/ESP32/SSDCK: R508.1, U504.21 (B1)
/ESP32/USB_OTG_JTAG_D+: J502.3 (D+), U505.26 (GPIO20/USB_D+)
/ESP32/USB_OTG_JTAG_D-: J502.2 (D-), U505.25 (GPIO19/USB_D-)
/ESP32/~AUX_RESET: J503.5, U505.36 (GPIO39/MTCK)
/ESP32/~AUX_SPI_CS0: J503.3, U505.16 (GPIO10/ADC1_CH9)
/ESP32/~AUX_SPI_CS1: J503.4, U505.20 (GPIO14/ADC2_CH3)
/ESP32/~BIORQ_A4_RD: U505.34 (GPIO37), U509.4 (Y)
/ESP32/~BIORQ_A4_WR: U505.33 (GPIO36), U508.4 (Y)
/ESP32/~BOOT: C508.1, S502.1, U505.31 (GPIO0)
/ESP32/~ESP_RESET: C506.1, S501.1, U505.3 (CHIP_PU)
/ESP32/~ESP_SPI_CS0: R501.2, U501.1 (~OE), U504.5 (A3), U504.22 (OE), U505.27 (GPIO21)
/ESP32/~ESP_SPI_CS1: R507.2, U502.7 (A5), U503.1 (~OE), U505.32 (GPIO35)
/RS232/RS232_DOWNLOAD_RX: J401.2, U401.13 (R1IN)
/RS232/RS232_DOWNLOAD_TX: J401.3, U401.14 (T1OUT)
/RS232/RS232_Z80_RX: J403.2, U401.8 (R2IN)
/RS232/RS232_Z80_TX: J403.3, U401.7 (T2OUT)
/RS232/UART01_RX: J404.4, U401.12 (R1OUT)
/RS232/UART01_TX: J404.3, U401.11 (T1IN)
/SPI<->Z80 Bus/ADD_1A: R309.2, U301.16 (A1), U301.17 (A2), U301.18 (~RESET)
/SPI<->Z80 Bus/ADD_1B: R308.2, U302.17 (A2), U302.18 (~RESET)
/SPI<->Z80 Bus/SPI_1A_MISO: R306.1, U301.14 (SO)
/SPI<->Z80 Bus/SPI_1B_MISO: R307.1, U302.14 (SO)
/Z80 Retro Interface/BD0: RN201.2 (R1), U204.2 (O0), U205.2 (I0a), U206.18 (B1)
/Z80 Retro Interface/BD1: RN201.3 (R2), U204.5 (O1), U205.4 (I1a), U206.17 (B2)
/Z80 Retro Interface/BD2: RN201.4 (R3), U204.6 (O2), U205.6 (I2a), U206.16 (B3)
/Z80 Retro Interface/BD3: RN201.5 (R4), U204.9 (O3), U205.8 (I3a), U206.15 (B4)
/Z80 Retro Interface/BD4: RN201.6 (R5), U204.12 (O4), U205.11 (I0b), U206.14 (B5)
/Z80 Retro Interface/BD5: RN201.7 (R6), U204.15 (O5), U205.13 (I1b), U206.13 (B6)
/Z80 Retro Interface/BD6: RN201.8 (R7), U204.16 (O6), U205.15 (I2b), U206.12 (B7)
/Z80 Retro Interface/BD7: RN201.9 (R8), U204.19 (O7), U205.17 (I3b), U206.11 (B8)
/Z80 Retro Interface/~INT: J2.16, Q201.3 (C)
/Z80 Retro Interface/~IORQ_AX: U201.9 (O6), U202.5 (E2)
A0: J2.30, U202.2 (A1), U301.1 (GPB0)
A1: J2.31, U202.3 (A2), U301.2 (GPB1)
A2: J2.32, U202.6 (E3), U301.3 (GPB2)
A3: J2.33, U202.4 (E1), U301.4 (GPB3)
A4: J2.34, U201.1 (A0), U301.5 (GPB4)
A5: J2.35, U201.2 (A1), U301.6 (GPB5)
A6: J2.36, U201.4 (E1), U301.7 (GPB6)
A7: J2.37, U201.3 (A2), U301.8 (GPB7)
A8: J2.38, U301.21 (GPA0)
A9: J2.39, U301.22 (GPA1)
A10: J2.40, U301.23 (GPA2)
A11: J2.1, U301.24 (GPA3)
A12: J2.2, U301.25 (GPA4)
A13: J2.3, U301.26 (GPA5)
A14: J2.4, U301.27 (GPA6)
A15: J2.5, U301.28 (GPA7)
D0: J2.14, U204.3 (D0), U205.18 (O0a), U302.21 (GPA0)
D1: J2.15, U204.4 (D1), U205.16 (O1a), U302.22 (GPA1)
D2: J2.12, U204.7 (D2), U205.14 (O2a), U302.23 (GPA2)
D3: J2.8, U204.8 (D3), U205.12 (O3a), U302.24 (GPA3)
D4: J2.7, U204.13 (D4), U205.9 (O0b), U302.25 (GPA4)
D5: J2.9, U204.14 (D5), U205.7 (O1b), U302.26 (GPA5)
D6: J2.10, U204.17 (D6), U205.5 (O2b), U302.27 (GPA6)
D7: J2.13, U204.18 (D7), U205.3 (O3b), U302.28 (GPA7)
ESP_D0: RN202.2 (R1), U206.2 (A1), U505.11 (GPIO18/ADC2_CH7)
ESP_D1: RN202.3 (R2), U206.3 (A2), U505.10 (GPIO17/ADC2_CH6)
ESP_D2: RN202.4 (R3), U206.4 (A3), U505.9 (GPIO16/ADC2_CH5/32K_N)
ESP_D3: RN202.5 (R4), U206.5 (A4), U505.8 (GPIO15/ADC2_CH4/32K_P)
ESP_D4: RN202.6 (R5), U206.6 (A5), U505.7 (GPIO7/ADC1_CH6)
ESP_D5: RN202.7 (R6), U206.7 (A6), U505.6 (GPIO6/ADC1_CH5)
ESP_D6: RN202.8 (R7), U206.8 (A7), U505.5 (GPIO5/ADC1_CH4)
ESP_D7: RN202.9 (R8), U206.9 (A8), U505.4 (GPIO4/ADC1_CH3)
ESP_DATA_DIR5_W: U204.1 (OE), U502.16 (B6)
ESP_DATA_DIR_W: R504.2, R512.2, R514.2, U206.1 (DIR), U502.8 (A6)
GND: C101.2, C201.2, C202.2, C203.2, C204.2, C205.2, C206.2, C207.2, C208.2, C209.2, C210.2, C301.2, C302.2, C303.2, C304.2, C305.2, C401.2, C402.2, C405.2, C406.2, C501.2, C502.2, C503.2, C504.2, C505.2, C506.2, C507.2, C508.2, C509.2, C510.2, C511.2, C512.2, C513.2, C514.2, C515.2, D102.1, J2.29, J101.1, J102.1, J103.1, J104.1, J401.0 (PAD), J401.5, J402.5, J402.6, J403.0 (PAD), J403.5, J501.6 (VSS), J501.SH1 (SHIELD), J501.SH2 (SHIELD), J501.SH3 (SHIELD), J501.SH4 (SHIELD), J502.5 (GND), J502.6 (Shield), J503.2, J503.8, J503.10, Q201.1 (E), Q301.1 (E), Q302.1 (E), Q303.1 (E), S301.2, S501.2, S501.SH1, S501.SH2, S502.2, S502.SH1, S502.SH2, U101.3 (GND), U201.8 (GND), U202.8 (GND), U203.1 (ADJ/GND), U204.10 (GND), U205.10 (GND), U206.10 (GND), U206.19 (OE), U301.10 (VSS), U301.15 (A0), U302.10 (VSS), U302.15 (A0), U302.16 (A1), U401.15 (GND), U501.3 (GND), U502.9 (A7), U502.10 (A8), U502.11 (GND), U502.12 (GND), U502.13 (GND), U502.22 (OE), U503.3 (GND), U504.6 (A4), U504.7 (A5), U504.8 (A6), U504.9 (A7), U504.10 (A8), U504.11 (GND), U504.12 (GND), U504.13 (GND), U505.22 (GND), U505.23 (GND), U505.24 (GND), U505.44 (GND), U508.1 (~OE), U508.3 (GND), U509.1 (~OE), U509.3 (GND), Z201.2
unnamed: C301.1, R301.2, R304.1, S301.3
unnamed: D102.2, R102.2
unnamed: J202.1, R201.2
unnamed: Q201.2 (B), R201.1
unnamed: Q301.2 (B), Q302.3 (C), R302.2
unnamed: Q302.2 (B), R304.2
unnamed: Q303.2 (B), R305.2
unnamed: R102.1, U101.4 (Y)
unnamed: R305.1, U302.1 (GPB0)
unnamed: C403.2, U401.1 (C1+)
unnamed: C403.1, U401.3 (C1-)
unnamed: C404.1, U401.4 (C2+)
unnamed: C404.2, U401.5 (C2-)
unnamed: C405.1, U401.2 (VS+)
unnamed: C406.1, U401.6 (VS-)
SPI_1A_CLK: R505.2, U301.12 (SCK)
SPI_1A_MOSI: U301.13 (SI), U502.19 (B3)
SPI_1B_CLK: R506.2, U302.12 (SCK)
SPI_1B_MOSI: U302.13 (SI), U502.18 (B4)
SPI_1_MISO: R306.2, R307.2, U503.2 (A)
SPI_CS1: U301.11 (~CS), U302.11 (~CS), U502.17 (B5)
UART0_RX: J402.3, J404.2, U505.42 (GPIO44/U0RXD)
UART0_TX: J402.1, J404.1, U505.43 (GPIO43/U0TXD)
UART1_RX: J404.6, U505.40 (GPIO2/ADC1_CH1)
UART1_TX: J404.5, U505.41 (GPIO1/ADC1_CH0)
UART2_RX: J402.4, U401.9 (R2OUT), U505.38 (GPIO41/MTDI)
UART2_TX: J402.2, U401.10 (T2IN), U505.37 (GPIO40/MTDO)
Z80_INT: J202.2, U505.39 (GPIO42/MTMS)
~BUSACK: J2.23, U302.7 (GPB6)
~BUSRQ: J2.25, U302.6 (GPB5)
~IORQ_A4_RD: U202.15 (O0), U205.1 (OEa), U205.19 (OEb), U509.2 (A)
~IORQ_A4_WR: U202.14 (O1), U204.11 (Cp), U508.2 (A)
~IORQ: J2.20, U201.5 (E2), U302.5 (GPB4)
~M1: J2.27, U201.6 (E3), U302.8 (GPB7)
~MREQ: J2.19, U302.4 (GPB3)
~RD: J2.21, U202.1 (A0), U302.2 (GPB1)
~RESET: J2.26, Q301.3 (C), Q303.3 (C), R303.2
~SPI_SD_CS0: J501.2 (DAT3/CD), R518.2, U101.2 (A), U504.19 (B3)
~WR: J2.22, U302.3 (GPB2)

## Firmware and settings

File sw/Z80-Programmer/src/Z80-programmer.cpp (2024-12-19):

 /****************************************************************************
 * 
 *    Z80-Retro! ESP Programmer
 *    Code & ESP Programmer Board by Denno Wiggle
 *    Z80-Retro project by John Winans
 *     - https://github.com/Z80-Retro
 * 
 *****************************************************************************
 *
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
 *****************************************************************************/
#include <Arduino.h>
#include <HardwareSerial.h>
#include <stdio.h>
#include <LittleFS.h>
#include <EEPROM.h>

#include "defines.h"
#include "wtmSPi.h"
#include "version.h"
#include "wtmProgrammer.h"
#include "wServer.h"
#include "wtmSerialx.h"
#include "telnetServer.h"
#include "Z80IoBus.h"
// Todo : delete when we no longer need to test FPGA flash
#include "wtmFpga.h"

// Todo : DELETE
#include "sdcardtest.h"
#include "flash.h"



#ifdef WTM_PROG_I2C
#include <Wire.h>
#endif

#ifdef ESP32_TYPE_MCU
#include <WebServer.h>
#include "esp_efuse.h"
#include "esp_efuse_table.h"
#endif /* ESP2866_TYPE_MCU */

#ifdef ESP2866_TYPE_MCU
#include <ESP8266WebServer.h>
#endif /* ESP32_TYPE_MCU */

#include <WiFiClient.h>

// UART Port mapping
// Map Console port to Serial1 / uart 1 Tx/Rx
HardwareSerial *uartA = new HardwareSerial(1);
// Map logger to Serial / uart 0 Tx Only
HardwareSerial *uartB = new HardwareSerial(0);
#ifdef ESP32_TYPE_MCU
// Map Z80 to Serial2 / uart 2 Tx/Rx
HardwareSerial *uartC = new HardwareSerial(2);
#else
HardwareSerial *uartC = &Serial;
#endif

wtmProgrammer flashProgrammer;
wtmSerialX* console;
wtmSerialX* logger;
// wtmSerialX* telnetSerial;
wtmSerialX* z80uart;
wtmSerialX* xmodemUart;



typedef enum mode
{
    MENU,
    PROGRAMMING,
    DEBUG,
    CHANGE_BAUD
} Mode;
Mode _mode;


uint8_t ledState = LED_OFF;

void printFileContentsAsText(char *filename)
{
    if(!LittleFS.begin()){
        console->printf("An Error has occurred while mounting LittleFS\r\n");
        return;
    }
  
    File file = LittleFS.open(filename, "r");
    if(!file){
        console->printf("Failed to open file for reading\r\n");
        return;
    }
  
    console->printf("File Content:\r\n");
    while(file.available()){
        Serial.write(file.read());
    }
    file.close();
}

// showLittleFsInfo() taken from : 
// https://www.mischianti.org/2020/06/22/wemos-d1-mini-esp8266-integrated-littlefs-filesystem-part-5/
// website has a list of commands available in LittleFS
#ifndef ESP32   // Not supported in ESP32
void showLittleFsInfo()
{
    console->printf("Inizializing FS...");
    if (LittleFS.begin()){
        console->printf("done.\r\n");
    }else{
        Serial.println("fail.\r\n");
    }

    // To format all space in LittleFS
    // LittleFS.format()

    // Get all information of your LittleFS
    FSInfo fs_info;
    LittleFS.info(fs_info);

    console->printf("File sistem info.\r\n");
    console->printf("Total space:      %d bytes\r\n", fs_info.totalBytes);
    console->printf("Total space used: %d bytes\r\n", fs_info.usedBytes);
    console->printf("Block size:       %d bytes\r\n", fs_info.blockSize);
    console->printf("Page size:        %d bytes\r\n", fs_info.totalBytes);
    console->printf("Max open files:   %d\r\n", fs_info.maxOpenFiles);
    console->printf("Max path length:  %d\r\n\n", fs_info.maxPathLength);

    console->printf("File - Size :\r\n");
    // Open dir folder
    Dir dir = LittleFS.openDir("/");
    // Cycle all the content
    while (dir.next()) {
        // get filename
        console->printf("   %s - ", dir.fileName().c_str());
        // If element have a size display It else write 0
        if(dir.fileSize()) {
            File f = dir.openFile("r");
            console->printf("%d\r\n",f.size());
            f.close();
        }else{
            console->printf("0\r\n");
        }
    }
}

void testLittleFS()
{
    console->printf("\r\nTest LittleFS\r\n");
    console->printf("-------------\r\n");
    showLittleFsInfo();
    //printFileContentsAsText((char *)"/text.txt");
}
#endif

#ifdef WTM_PROG_I2C
void scanI2cBus()
{
    uint8_t error, address;
    int nDevices = 0;

    console->printf("\r\nScanning...\r\n");
    for(address = 1; address < 127; address++ ) {
        Wire.beginTransmission(address);
        error = Wire.endTransmission();
        if (error == 0) {
            console->printf("I2C device found at address 0x%2x\r\n", address);
            nDevices++;
        }
        else if (error == 4) 
        {
            console->printf("Unknow error at address 0x%2x\r\n", address);
        }
    }
    if (nDevices == 0) {
        console->printf("No I2C devices found\r\n");
    } else {
        console->printf("done\r\n\n");
    }
}
#endif
void displayMenu() {
    // So we know what version we are running
    console->printf("\r\n###########################\r\n");
    console->printf("#  Z80 Retro! Programmer  #\r\n");
    console->printf("###########################\r\n");
    //console->printf("\n----------------\r\n");

    if (_mode == MENU)
    {
        console->printf("Main Menu\r\n");
        console->printf("----------------\r\n");        
        console->printf("p for programming mode\r\n");
        console->printf("d for debug mode\r\n");
#ifndef ESP32_TYPE_MCU
        // ESP2866 share console and z80uart so cannot cross connect the two
        // so need to remove that option
        uint8_t conCfg = console->portCfg();
        console->disablePort(SX_UART_A);
#endif
        console->printf("z to connect Z80 UART\r\n");
        if (z80uart->portCfg() > 0) {
            console->printf("o to disconnect Z80 UART and reconnect console on Serial 0 (USB)\r\n");
        }

#ifndef ESP32_TYPE_MCU
        console->enablePort(conCfg);
#endif
        console->printf("r to reset Z80 Retro\r\n");
        console->printf("b to change Z80 uart baudrate [%d]\r\n", z80uart->baudRate);
        console->printf("c to clear wifi settings\r\n");
        console->printf("w to display wifi settings\r\n");
    }
    else if (_mode == CHANGE_BAUD)
    {
        console->printf("Change Z80 Uart Baud Rate Menu [%d]\r\n", z80uart->baudRate);
        console->printf("---------------------------------------\r\n");        
        console->printf("0 =    300\r\n");
        console->printf("1 =    600\r\n");
        console->printf("2 =   1200\r\n");
        console->printf("3 =   2400\r\n");
        console->printf("4 =   4800\r\n");
        console->printf("5 =   9600\r\n");
        console->printf("6 =  14400\r\n");
        console->printf("7 =  19200\r\n");
        console->printf("8 =  28800\r\n");
        console->printf("9 =  38400\r\n");
        console->printf("a =  57600\r\n");
        console->printf("b = 115200\r\n");
        console->printf("m to return to menu\r\n");
    }
    else if (_mode == PROGRAMMING)
    {
        uint16_t addr = flashProgrammer.getReadAddr();
        uint8_t flashType = flashProgrammer.getFlashType();
        console->printf("Programming Menu (%s)\r\n", 
                (flashType == flashProgrammer.Z80_FLASH) ? "Z80 Flash" : "FPGA Flash");
        console->printf("-----------------------------\r\n"); 
        // xmodem is only supported on UARTA or telnet ports
        uint8_t conCfg = console->portCfg();
        console->disablePort(0xFF & ~(SX_UART_A | SX_TELNET_PORTS) );
        console->printf("c to change Flash to %s\r\n",
                (flashType == flashProgrammer.Z80_FLASH) ? "FPGA Flash" : "Z80 Flash");
        console->printf("p to program (requires a terminal capable of xmodem)\r\n");
        console->enablePort(conCfg);
        console->printf("a to advance address [%04x]\r\n", addr);
        console->printf("z to zero address [%04x]\r\n", addr);
        console->printf("r to read [%04x]\r\n", addr);
        console->printf("e to erase\r\n");
        console->printf("d to debug write/read\r\n");
        console->printf("v to toggle verbose programming (%s)\r\n",
                    flashProgrammer.getVerboseProgramming()? "ON" : "OFF");
        console->printf("m to return to menu\r\n");
    }
    else if (_mode == DEBUG)
    {
        console->printf("Debug Menu\r\n");
        console->printf("----------------\r\n");        
#ifdef WTM_PROG_I2C
        console->printf("s to scan i2c bus\r\n");
#endif
        console->printf("f to read FPGA flash ID\r\n");
        console->printf("i to read Z80 flash ID\r\n");
        console->printf("t to test Fpga flash\r\n");
#ifndef ESP32_TYPE_MCU  // Not supported on ESP32         
        console->printf("f to show LittleFS contents\r\n");
#endif
        console->printf("d to test micro SD card\r\n");
        console->printf("r to read the Z80 message port\r\n");
        console->printf("w to write to the Z80 message port\r\n");
        console->printf("m to return to menu\r\n");
    }
    console->printf("----------------\r\n\n");
}

void menuCommand(unsigned char opt)
{
    uint8_t portId;
    uint8_t portCfg;
    switch (opt)
    {
        case 'p':
            _mode = PROGRAMMING;
            break;
        case 'd':
            _mode = DEBUG;
            break;
        case 'z':
            portId = console->readPortId();

            // Close console on this port and connect Z80 UART to it
            // Print a closing message only to port that commanded 'z'
            portCfg = console->portCfg();
            console->disablePort(portCfg & ~portId);
            console->printf("\r\n***** ESP User terminal disconnected *****\r\n");
            console->enablePort(portCfg);
            // Now turn off the console for the port that commanded 'z'
            console->flush();
            console->disablePort(portId);
#ifdef ESP2866_TYPE_MCU
            swapUartAUartC(true);
#endif
            // enable z80uart cross connect on port where 'z' read
            z80uart->enablePort(portId);
            // Send the connection message to all active users
            z80uart->printf("\r\n***** Z80 User terminal connected    *****\r\n");
            break;

        case 'o':
            if (z80uart->portCfg() & SX_UART_A)
            {
                // Close access to z80uart on port A and connect the ESP console to it
                // Print a closing message on the z80uart channel for uart A only.
                portCfg = z80uart->portCfg();
                z80uart->disablePort(portCfg & ~SX_UART_A);
                z80uart->printf("\r\n***** Z80 User terminal disconnected *****\r\n");
                z80uart->enablePort(portCfg);
                z80uart->flush();
                z80uart->disablePort(SX_UART_A);
#ifdef ESP2866_TYPE_MCU
                swapUartAUartC(false);
#else
                // Reconnect console
                // Enable console on uart A
                portCfg = console->portCfg();
                console->disablePort(portCfg);
                console->enablePort(SX_UART_A);
                console->printf("\r\n***** ESP User terminal connected    *****\r\n");
                console->enablePort(portCfg);
#endif
            }
            break;
        case 'b':
            _mode = CHANGE_BAUD;
            break;
        case 'c':
            clearWifiSettings();
            break;
        case 'r':
            flashProgrammer.resetZ80();
            break;
        case 'w':
            displayWifiSettings();
            break;
        default:
            break;
    }
}


void programCommand(unsigned char opt)
{
    // int rc = 0;
    uint16_t addr = 0;
    uint8_t portId;
    bool oneByteMode;

    switch (opt)
    {
        case 'c':
            if (flashProgrammer.getFlashType() == flashProgrammer.Z80_FLASH)
            {
                flashProgrammer.setFlashType(flashProgrammer.FPGA_FLASH);
            } else {
                flashProgrammer.setFlashType(flashProgrammer.Z80_FLASH);
            }
            break;
        case 'p':
            portId = console->readPortId();
            // Can only program with xmodem on UART A or telnet ports
            //if (portId == SX_UART_A) 
            if ( (portId == SX_UART_A) || (portId & SX_TELNET_PORTS) )
            {
                flashProgrammer.selectXmPort(portId);
                oneByteMode = console->oneByteOnlyMode;
                console->oneByteOnlyMode=false;
                console->flush();
                if (portId & SX_TELNET_PORTS) xmodemUart->fileTransferMode = true;
                flashProgrammer.programFlashFirmware();
                if (portId & SX_TELNET_PORTS) xmodemUart->fileTransferMode = false;
                console->oneByteOnlyMode = oneByteMode;
            }
            break;
        case 'a':
            addr = flashProgrammer.getReadAddr();
            flashProgrammer.incReadAddr();
            break;
        case 'z':
             flashProgrammer.zeroReadAddr();
            break;
        case 'r':
            addr = flashProgrammer.getReadAddr();
            flashProgrammer.selectBus();
            flashProgrammer.readOneFlashBlock(addr, BLOCK_SIZE, true);
            flashProgrammer.releaseBus();
            flashProgrammer.incReadAddr();
            break;        
        case 's':
            flashProgrammer.selectBus();
            flashProgrammer.save64kFlashToFile();
            flashProgrammer.releaseBus();
            break;        
        case 'e':
            flashProgrammer.selectBus();
            flashProgrammer.eraseFlash();
            flashProgrammer.releaseBus();
            break;
        case 'd':
            flashProgrammer.selectBus();
            flashProgrammer.debugWriteRead();
            flashProgrammer.releaseBus();
            break;
        case 'b':
            break;
        case 'v':
            flashProgrammer.toggleVerboseProgramming();
            break;
        case 'm':
            _mode = MENU;
            break;
        default:
            break;
    } 
}


void debugCommand(unsigned char opt)
{
    switch (opt)
    {
        case 'f':
            flashProgrammer.setFlashType(flashProgrammer.FPGA_FLASH);
            flashProgrammer.selectBus();
            flashProgrammer.readFlashId();
            flashProgrammer.releaseBus();
            break;

        case 'i':
            flashProgrammer.setFlashType(flashProgrammer.Z80_FLASH);
            flashProgrammer.selectBus();
            flashProgrammer.readFlashId();
            flashProgrammer.releaseBus();
            break;

        case 't':
            flashProgrammer.setFlashType(flashProgrammer.FPGA_FLASH);
            flashProgrammer.selectBus();
            testFpgaFlash();
            flashProgrammer.releaseBus();
            break;

#ifdef WTM_PROG_I2C
        case 's':
            // scan i2c bus
            scanI2cBus();
            break;
#endif
#ifndef ESP32_TYPE_MCU    // Not supported on ESP32          
        case 'f':
            // show LittleFS contents
            testLittleFS();
            break;
#endif
        case 'd':
            console->printf("\r\n###################################\r\n");
            console->printf("Test the SPI bus without SD Card SW\r\n");
            console->printf("###################################\r\n");
            lowLevelSpiTest(false);
            delay(1000);
            console->printf("\r\n###################################\r\n");
            console->printf("Test the SPI bus with SD Card SW\r\n");
            console->printf("###################################\r\n");
            lowLevelSpiTest(true);
            break;
        case 'r':
            console->printf("\r\nZ80 Data 8-bit data port reads 0x%02x\r\n", z80DataPortRead());
            break;
        case 'w':
        {
            uint8_t z80data = 0x55;
            console->printf("\r\nZ80 Data 8-bit data port write 0x%02x\r\n", z80data);
            z80DataPortwrite(z80data);
        }
            break;
        case 'm':
            _mode = MENU;
            break;
        default:
            break;
    }

}

void changeBaudCommand(unsigned char opt)
{
    wtmSerialX::baudRate_t oldBaud = z80uart->baudRate;
    wtmSerialX::baudRate_t newBaud = oldBaud;
    switch (opt)
    {
        case '0':
            newBaud = z80uart->baud300;
            break;
        case '1':
            newBaud = z80uart->baud600;
            break;
        case '2':
            newBaud = z80uart->baud1200;
            break;
        case '3':
            newBaud = z80uart->baud2400;
            break;
        case '4':
            newBaud = z80uart->baud4800;
            break;
        case '5':
            newBaud = z80uart->baud9600;
            break;
        case '6':
            newBaud = z80uart->baud14400;
            break;
        case '7':
            newBaud = z80uart->baud19200;
            break;
        case '8':
            newBaud = z80uart->baud28800;
            break;
        case '9':
            newBaud = z80uart->baud38400;
            break;
        case 'a':
            newBaud = z80uart->baud57600;
            break;
        case 'b':
            newBaud = z80uart->baud115200;
            break;
        case 'm':
            _mode = MENU;
            break;
        default:
            break;
    }

    if (newBaud != oldBaud)
    {
        z80uart->baudRate = newBaud;
        EEPROM.put(sizeof(wifiSettings), z80uart->baudRate);
        EEPROM.commit();

        if (z80uart->portCfg() > 0)
        {
            uartC->flush();
            uartC->end();
            uartC->begin(newBaud);
#ifndef ESP32_TYPE_MCU
            if (z80uart->boolUartASwapped)
            {
                uartA->swap();
            }
            // Flush the Rx buffer
            while(uartC->available())
            {
                uartC->read();
            }
#endif
        }
    }

}


void doCommand(unsigned char opt)
{
    if (_mode == MENU)
    {
        menuCommand(opt);
    }
    else if (_mode == PROGRAMMING)
    {
        programCommand(opt);
    }
    else if (_mode == DEBUG)
    {
        debugCommand(opt);
    }
    else if (_mode == CHANGE_BAUD)
    {
        changeBaudCommand(opt);
    }
}
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
void loop() {

    // Handles the setup of Wifi Network in AP mode
    handleClient();

    // Handles the telnet connection.
    handleTelnet();

#ifdef WTM_PROG_SPI
    // Handles the plugging and unplgging of SD cards
    handleSdCardEvents();
#endif

#ifdef WTM_TEST_Z80_MESSAGE_INTERFACE
    // for board bring-up test to test automatic reading and writing to the Z80.
    // Need to run esp32rw.com on the z80 for this code to run. 
    // Low-level board test only! Disables normal IRQ finction.
    handleZ80IorqTest();
#endif

#ifndef WTM_TEST_Z80_MESSAGE_INTERFACE
     // Lets us know the Z80 activity on the IORQ A0 Read and Write pins
   handleZ80Iorq();
#endif

    // Cross connect uartC to another uart or telnet
    if (z80uart->portCfg() > 0)
        handleXconnect();

    // Here we check if there has been a web request to program firmware
    // that we need to go perform
    // If not check the serial port for a command.
    if (!flashProgrammer.updateProgramming())
    {
        // Here we control the console menus.
        if (console->available() > 0)
        {
            logger->printf("console->available() = 0x%02x\r\n", console->available() );
            logger->printf("console->readPortId() = 0x%02x\r\n", console->readPortId() );
            unsigned char b;
            size_t len = console->readBytes(&b, 1, console->readPortId());

            if (len > 0) {
                // Serial.printf("Bytes available = %d\r\n", len);
                bool oneByteMode = console->oneByteOnlyMode;
                console->oneByteOnlyMode=true;
                doCommand(b);
                console->oneByteOnlyMode = oneByteMode;
                displayMenu();
            }
        }
    }
}

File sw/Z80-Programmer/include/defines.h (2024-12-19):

//****************************************************************************
//
//  Global defines for the project
//
//****************************************************************************
#ifndef __DEFINES_H__
#define __DEFINES_H__


//****************************************************************************
//
//  ESP module specific defines
//
//****************************************************************************

// Defines for ESP32 based boards.  Uncomment the one in use
// Note : platformio.ini needs to be modified to specify board as well
// Version needs to be set for V1.0 ESP32_S3_DEVKITC hardware boards to enable 
// swapping the LED port
#define ESP32_S3_DEVKITC
#define ESP32_S3_DEVKITC_VERSION (1)
//#define ESP32_ESP_WROOM_32_DEVKIT

// Defines for ESP2866 based boards.  Uncomment the one in use
// Note : platformio.ini needs to be modified to specify board as well
// Note : ESP2866_12E is a ESP2866 Node MCU ESP-12E
// #define ESP2866_NODE_MCU_12E
// #define ESP2866_WEMOS_D1_MINI

#if ( defined( ESP32_S3_DEVKITC ) || defined( ESP32_ESP_WROOM_32_DEVKIT ) )
    #define ESP32_TYPE_MCU
#else 
    #define ESP2866_TYPE_MCU
#endif

#define WTM_PROG_I2C


#ifdef ESP32_TYPE_MCU
    #ifdef ESP32_S3_DEVKITC
        #define TXD0 (43)
        #define RXD0 (44)
        #define TXD1 (1)
        #define RXD1 (2)
        #define TXD2 (40)
        #define RXD2 (41)

        #undef WTM_PROG_I2C
        #define WTM_PROG_SPI
        #define SCL (36)
        #define SDA (37)

        /* ESP32_S3_DEVKITC use LED on GPIO 48 (V1) or 38 (V1.1)*/
        // so some pin swap needed per version */
        // DP Todo - In future see if we can remove need to hardcode
        // Note - This is an RGB LED so while RGB_CTRL is connected to 
        // GPIO38/48 it is controlled on/off via GPIO LED_BUILTIN (97) */
        #if ESP32_S3_DEVKITC_VERSION == 1
            //ESP32_S3_DEVKITC V1
            #define LED_PIN        (LED_BUILTIN)
            // #define LED_PIN        (48)
            #define WTM_RGB_PIN    (RGB_BUILTIN)
            #define ESP_DATA_DIR_R (38)
        #else // ESP32_S3_DEVKITC V1.1
            #define LED_PIN        (LED_BUILTIN)
            // #define LED_PIN        (38)
            #define WTM_RGB_PIN    (RGB_BUILTIN)
            #define ESP_DATA_DIR_R (48)
        #endif /*  ESP32_S3_DEVKITC_VERSION == 1 */

        #define WTM_SPI_HOST_SD     (SPI2_HOST)
        #define WTM_SPI_SD_MOSI     (47)
        #define WTM_SPI_SD_MISO     (45)
        #define WTM_SPI_SD_CLK      (9)
        #define WTM_SPI_SD_CS0      (21)
        #define WTM_SPI_IO_EXP_CS1  (35)
        #define WTM_SPI_SD_CD       (8)
        // Work around for Rev 0 board where SD bus is
        // shared with other devices with no isolation
        // of MOSI.
        // Set to 1 if Rev 0 board.
        #define WTM_SPI_WORKAROUND  (0)
        
        // According to the datasheet these pins are FSPI = SPI2_HOST
        // However SPI SD crashes if AUX delared after SD bus.
        // No crash if set to SPI3_HOST
        #define WTM_SPI_HOST_AUX    (SPI3_HOST)
        #define WTM_SPI_AUX_MOSI    (11)
        #define WTM_SPI_AUX_MISO    (13)
        #define WTM_SPI_AUX_CLK     (12)
        #define WTM_SPI_AUX_CS0     (10)
        #define WTM_SPI_AUX_CS1     (14)
        #define WTM_AUX_RESET_N     (39)
        #define WTM_AUX_DONE        (3)

        #define WTM_SPI_SD_FREQ       (10000)  // 10MHz - SD card 20MHz max in MMC SPI mode.
        #define WTM_SPI_IO_EXP_FREQ   (10000)  // 10MHz - MCP23S17 10MHz max.
        #define WTM_SPI_AUX_FREQ      (10000)    // 400kHz
        // #define WTM_SPI_SD_FREQ       (400)    // 400kHz
        // #define WTM_SPI_IO_EXP_FREQ   (400)    // 400kHz
        // #define WTM_SPI_AUX_FREQ      (400)    // 400kHz

        #define Z80_DATA_0     (18)
        #define Z80_DATA_1     (17)
        #define Z80_DATA_2     (16)
        #define Z80_DATA_3     (15)
        #define Z80_DATA_4      (7)
        #define Z80_DATA_5      (6)
        #define Z80_DATA_6      (5)
        #define Z80_DATA_7      (4)
        #define Z80_DATA_DIR_W (38)
        #define Z80_INT_N      (42)

        #define Z80_IORQ_A0_RD (37)
        #define Z80_IORQ_A0_WR (36)
        
        #define USE_ON_BOARD_LED 

    #else /* Not ESP32_S3_DEVKITC */
        #define TXD0 (1)
        #define RXD0 (3)
        #define TXD1 (27)
        #define RXD1 (14)
        #define TXD2 (17)
        #define RXD2 (16)

        #define SCL (22)
        #define SDA (21)

        #define LED_PIN     (2)
        #define USE_ON_BOARD_LED 

        #define WTM_SD_MISO  (0)
        #define WTM_SD_MOSI  (0)
        #define WTM_SD_CLK   (0)
        #define WTM_SD_CS    (0)
        #define WTM_SD_CD    (0)
        #define WTM_SD_HOST  (0) 
    #endif /* ESP32_S3_DEVKITC_1 */
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

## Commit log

2023-07-31 Initial Board Release commit.
    [ESP32.kicad_sch, ESP32_Interface.kicad_pcb, ESP32_Interface.kicad_sch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]
2023-07-31 Initial Release
    [ESP32.kicad_sch, RS232.kicad_sch]
2023-07-31 Updated notes on schematic PDF.
2024-12-19 Add the gerbers
    [ESP32_Interface-B_Cu.gbl, ESP32_Interface-B_Mask.gbs, ESP32_Interface-B_Paste.gbp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]

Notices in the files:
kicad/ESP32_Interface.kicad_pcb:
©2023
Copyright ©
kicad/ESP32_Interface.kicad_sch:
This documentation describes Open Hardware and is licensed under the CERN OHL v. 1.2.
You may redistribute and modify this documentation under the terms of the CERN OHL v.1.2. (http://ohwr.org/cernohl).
